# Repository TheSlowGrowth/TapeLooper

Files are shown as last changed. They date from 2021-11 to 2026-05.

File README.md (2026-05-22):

# TapeLooper





A digital tape looper module for Eurorack or standalone use, built on the [Daisy Seed](https://electro-smith.com/product/daisy-seed/).

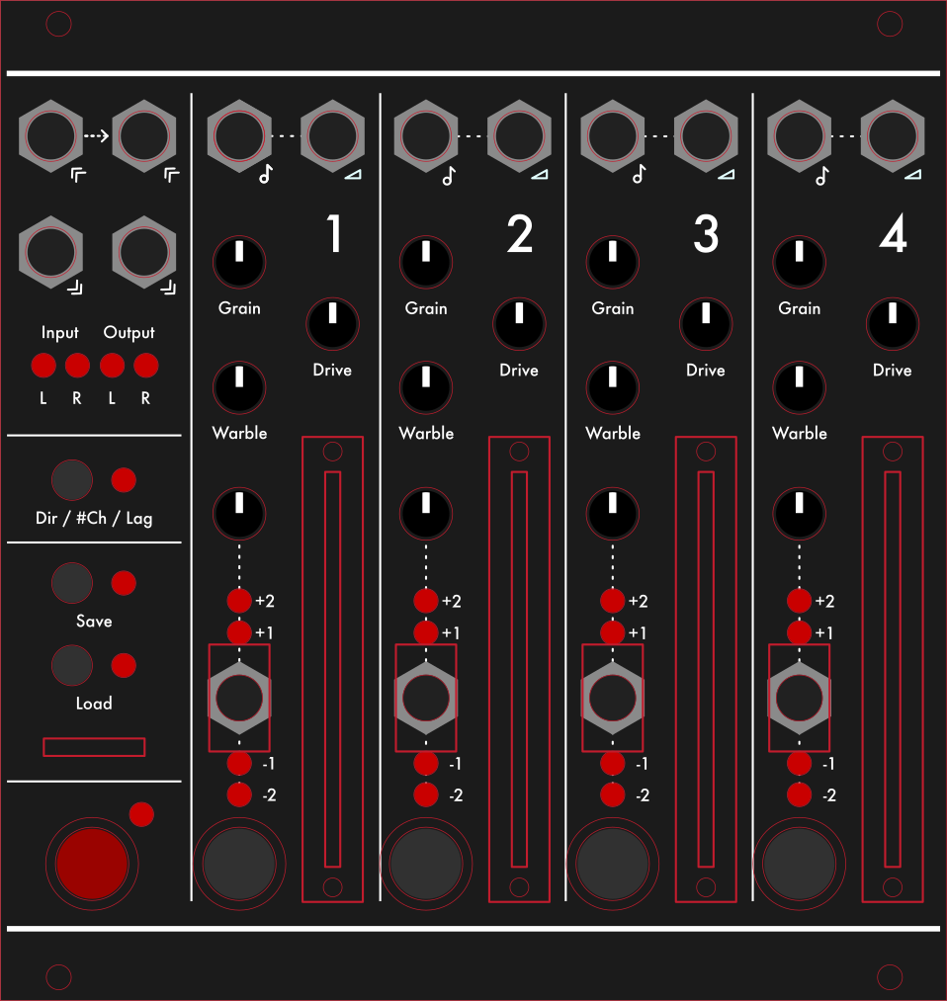
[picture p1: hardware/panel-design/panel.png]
panel design


## Features

- **4 stereo or mono tape loop channels** - record and play back independent, unsynchronized tape loops
- **Motor simulation** - playback speed ramps up and down with a configurable rate
- **Tape simulation** - with drive, grain and warble independently controllable
- **Variable playback speed** - with Volt/Octave CV control and quarter/half/double/quad speed
- **Forward and reverse playback**
- **Amplitude CV control**
- **Clean recording** — audio records cleanly into loop channels; tape simulation is applied during playback only
- **Perfect loop recording** - with a small crossfade at the loop point
- **SD card storage** - save and load loops as 48kHz stereo WAV files

## Hardware

Based on the Electrosmith Daisy Seed. Designed to operate as either a Eurorack module or a standalone desktop unit.

## Project Structure

- `dsp/` — DSP library: audio processing, loop playback/recording, tape simulation
- `firmware/` — Target firmware: main application, UI, SD card I/O
- `hardware/` — KiCad PCB designs and panel artwork
- `lib/` — External dependencies
- `scripts/` — Development helper scripts

## Development

### Requirements

- **CMake** 3.30+
- **clang++** (C++17) for building and running unit tests
- **arm-none-eabi-gcc** 10-2020-q4 recommended for cross-compiling firmware to the Daisy Seed
- **Python 3** with `pip` (for pre-commit hooks)

### Unit Tests

Tests are written with Google Test. Build and run from the respective `tests/` directories:

```bash
# DSP library tests
cd dsp/tests && make test

# Firmware tests
cd firmware/tests && make test
```

### Pre-commit Hook

A pre-commit hook runs `clang-format` on staged files before each commit. To install:

```bash
./scripts/setup-clangformat-precommit-hook.sh
```

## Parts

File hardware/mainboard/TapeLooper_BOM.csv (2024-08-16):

Reference | Value | Datasheet | Footprint | Qty | DNP
C101,C201,C401,C403 | 10u |  | Capacitor_SMD:C_0603_1608Metric_Pad1.08x0.95mm_HandSolder | 4
C102,C202,C402,C404,C601,C602,C603,C604,C702,C704,C803,C804,C808,C810,C903,C908 | 100n | -- mixed values -- | Capacitor_SMD:C_0603_1608Metric_Pad1.08x0.95mm_HandSolder | 16
C701,C703,C705,C706 | 560p |  | Capacitor_SMD:C_0603_1608Metric_Pad1.08x0.95mm_HandSolder | 4
C801,C805,C806,C811 | 4u7 | ~ | Capacitor_SMD:C_0603_1608Metric_Pad1.08x0.95mm_HandSolder | 4
C802,C807,C809 | 47u |  | Capacitor_SMD:CP_Elec_6.3x5.8 | 3
C901,C902,C904,C905,C906,C907,C909,C910 | 1n | ~ | Capacitor_SMD:C_0603_1608Metric_Pad1.08x0.95mm_HandSolder | 8
D201,D202,D203,D204,D205,D206,D207,D208,D401,D402,D403,D404,D405,D406,D407,D408,D409,D410,D411,D412,D413,D414,D415,D416 | LED_RED_GREEN_CA | ~ | LED_THT:LED_D3.0mm-3 | 24
D801,D802 | 1N5819 | http://www.vishay.com/docs/88525/1n5817.pdf | Diode_SMD:D_SOD-123 | 2
J101 | Micro_SD_Card | http://katalog.we-online.de/em/datasheet/693072010801.pdf | ell_connectors:PJS008U-3000 | 1
J701,J702,J703,J704,J901,J902,J903,J904,J905,J906,J907,J908 | PJ398SM |  | ell_connectors:THONKICONN | 12
J801 | Conn_02x05_Odd_Even | ~ | Connector_IDC:IDC-Header_2x05_P2.54mm_Vertical | 1
JP801 | SolderJumper_2_Bridged | ~ | Jumper:SolderJumper-2_P1.3mm_Bridged2Bar_RoundedPad1.0x1.5mm | 1
L801,L802 | Bead |  | Inductor_SMD:L_0603_1608Metric_Pad1.05x0.95mm_HandSolder | 2
L803,L804 | 4.7mH | ~ | Inductor_SMD:L_1210_3225Metric_Pad1.42x2.65mm_HandSolder | 2
R101,R102,R103,R104,R105,R106,R219 | 47k | ~ | Resistor_SMD:R_0603_1608Metric_Pad0.98x0.95mm_HandSolder | 7
R201,R202,R203,R204,R205,R206,R207,R208,R209,R210,R211,R212,R213,R214,R215,R216,R401,R402,R403,R404,R405,R406,R407,R408,R409,R410,R411,R412,R413,R414,R415,R416,R417,R418,R419,R420,R421,R422,R423,R424,R425,R426,R427,R428,R429,R430,R431,R432 | 330 | ~ | Resistor_SMD:R_0603_1608Metric_Pad0.98x0.95mm_HandSolder | 48
R217,R218 | 4k7 | ~ | Resistor_SMD:R_0603_1608Metric_Pad0.98x0.95mm_HandSolder | 2
R220,R221,R222,R223,R301,R302,R303,R304,R305,R306,R307,R308,R309,R310,R311,R312 | 10k | ~ | Resistor_SMD:R_0603_1608Metric_Pad0.98x0.95mm_HandSolder | 16
R701,R703,R707,R710,R901,R903,R907,R909,R913,R915,R919,R921 | 100k | -- mixed values -- | Resistor_SMD:R_0603_1608Metric_Pad0.98x0.95mm_HandSolder | 12
R702,R704,R706,R709 | 8k2 |  | Resistor_SMD:R_0603_1608Metric_Pad0.98x0.95mm_HandSolder | 4
R705,R708 | 1k |  | Resistor_SMD:R_0603_1608Metric_Pad0.98x0.95mm_HandSolder | 2
R801,R802 | 2k2 | ~ | Resistor_SMD:R_0603_1608Metric_Pad0.98x0.95mm_HandSolder | 2
R902,R908,R914,R920 | 78k7 | ~ | Resistor_SMD:R_0603_1608Metric_Pad0.98x0.95mm_HandSolder | 4
R904,R910,R916,R922 | 68k | ~ | Resistor_SMD:R_0603_1608Metric_Pad0.98x0.95mm_HandSolder | 4
R905,R911,R917,R923 | 481k | ~ | Resistor_SMD:R_0603_1608Metric_Pad0.98x0.95mm_HandSolder | 4
R906,R912,R918,R924 | 200k | ~ | Resistor_SMD:R_0603_1608Metric_Pad0.98x0.95mm_HandSolder | 4
RV501,RV502,RV503,RV504,RV509,RV510,RV511,RV512,RV513,RV514,RV515,RV516,RV517,RV518,RV519,RV520 | POTENTIOMETER |  | ell_passives:9mm_pot | 16
RV505,RV506,RV507,RV508 | PTA4543-2010CPB103 | ~ | Potentiometer_THT:Potentiometer_Bourns_PTA4543_Single_Slide | 4
SW201,SW202,SW203 | TL1105SPF250Q | ~ | Button_Switch_THT:SW_PUSH_6mm | 3
SW204 | D6R40F1LFS | ~ | ell_special:CK-D6R_Pushbutton | 1
SW301,SW303,SW305,SW307 | C&K 7105SYCQE | ~ | ell_special:7105SYCQE-1P3T-SP3T-Switch | 4
SW302,SW304,SW306,SW308 | D6R90F1LFS | ~ | ell_special:CK-D6R_Pushbutton | 4
U101 | DAISY_SEED |  | ell_special:Daisy_Seed | 1
U201,U401,U402 | PCA9685PW | http://www.nxp.com/documents/data_sheet/PCA9685.pdf | Package_SO:TSSOP-28_4.4x9.7mm_P0.65mm | 3
U601,U602,U603,U604 | 4051 | http://www.intersil.com/content/dam/Intersil/documents/cd40/cd4051bms-52bms-53bms.pdf | Package_SO:SO-16_3.9x9.9mm_P1.27mm | 4
U605,U606 | 74HC165 | https://assets.nexperia.com/documents/data-sheet/74HC_HCT165.pdf | Package_SO:SO-16_3.9x9.9mm_P1.27mm | 2
U701 | TL074 | -- mixed values -- | Package_SO:SOIC-14_3.9x8.7mm_P1.27mm | 1
U801 | LM4040DBZ-5 | http://www.ti.com/lit/ds/symlink/lm4040-n.pdf | Package_TO_SOT_SMD:SOT-23 | 1
U802,U804 | AZ1117-3.3 | https://www.diodes.com/assets/Datasheets/AZ1117.pdf | Package_TO_SOT_SMD:SOT-223-3_TabPin2 | 2
U803 | LM4040DBZ-10 | http://www.ti.com/lit/ds/symlink/lm4040-n.pdf | Package_TO_SOT_SMD:SOT-23 | 1
U805 | EC4SAW-24S05N |  | ell_special:EC4SAW_DC_DC_SIP8 | 1
U901,U902 | MCP6004 | http://ww1.microchip.com/downloads/en/DeviceDoc/21733j.pdf | Package_SO:SO-14_3.9x8.65mm_P1.27mm | 2

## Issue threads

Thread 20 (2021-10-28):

Check processing load on the ES Daisy board

TheSlowGrowth, 2021-10-28:
To understand how many channels we can do on the device, let's attempt to run the DSP code on the ES Daisy Seed and see how much channels we can handle concurrently.

TheSlowGrowth, 2021-11-20:
### Test results

from branch feature/TSG/hardware-performance-tests
- 4 stereo loopers
- 44.1kHz (requires [this PR in libDaisy](https://github.com/electro-smith/libDaisy/pull/438) to be merged)
- high shelf emphasis EQ removed to save cycles
- pre-gain removed to save cycles (it was unused anyway)
- mapping of UI controls is still missing

When all 4 loopers play back at 4x speed, we hit 90% processor utilisation. I think this could actually work :-)

Closed 2021-11-27.

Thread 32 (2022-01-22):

Replace JUCE plugin with VCV Rack module

TheSlowGrowth, 2022-01-22:
It makes a lot of sense to test the module in the form of a VCV Rack module plugin. We should replace the current JUCE plugin.

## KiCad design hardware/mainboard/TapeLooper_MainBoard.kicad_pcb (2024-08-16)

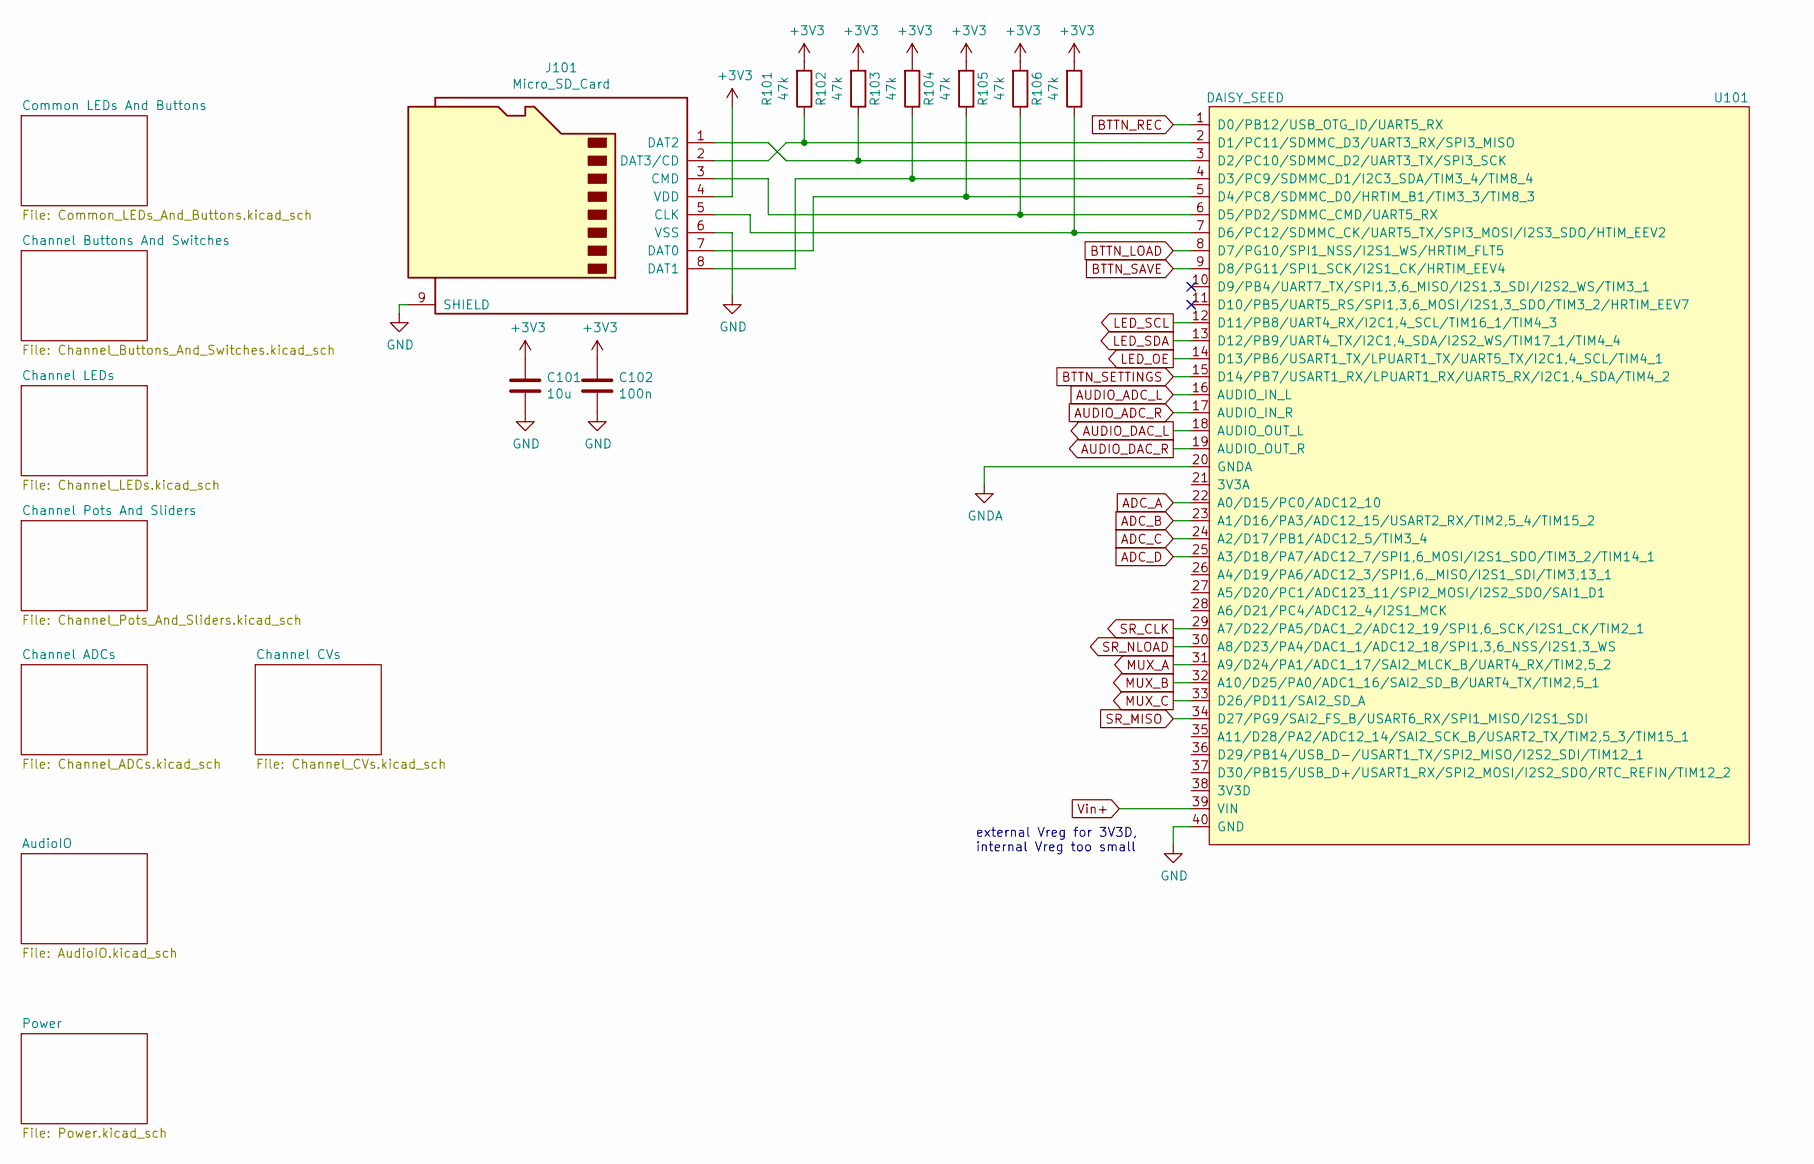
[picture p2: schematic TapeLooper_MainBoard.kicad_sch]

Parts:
C101: 10u; C_0603_1608Metric_Pad1.08x0.95mm_HandSolder
C102: 100n; C_0603_1608Metric_Pad1.08x0.95mm_HandSolder
J101: Micro_SD_Card; PJS008U-3000
R101, R102, R103, R104, R105, R106: 47k; R_0603_1608Metric_Pad0.98x0.95mm_HandSolder
U101: DAISY_SEED; Daisy_Seed

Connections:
+3V3: C101.1, C102.1, J101.4 (VDD), R101.2, R102.2, R103.2, R104.2, R105.2, R106.2; also elsewhere on the board
ADC_A: U101.22 (A0/D15/PC0/ADC12_10); also elsewhere on the board
ADC_B: U101.23 (A1/D16/PA3/ADC12_15/USART2_RX/TIM2,5_4/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); also elsewhere on the board
ADC_C: U101.24 (A2/D17/PB1/ADC12_5/TIM3_4); also elsewhere on the board
ADC_D: U101.25 (A3/D18/PA7/ADC12_7/SPI1,6_MOSI/I2S1_SDO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); also elsewhere on the board
AUDIO_ADC_L: U101.16 (AUDIO_IN_L); also elsewhere on the board
AUDIO_ADC_R: U101.17 (AUDIO_IN_R); also elsewhere on the board
AUDIO_DAC_L: U101.18 (AUDIO_OUT_L); also elsewhere on the board
AUDIO_DAC_R: U101.19 (AUDIO_OUT_R); also elsewhere on the board
BTTN_LOAD: U101.8 (D7/PG10/SPI1_NSS/I2S1_WS/HRTIM_FLT5); also elsewhere on the board
BTTN_REC: U101.1 (D0/PB12/USB_OTG_ID/UART5_RX); also elsewhere on the board
BTTN_SAVE: U101.9 (D8/PG11/SPI1_SCK/I2S1_CK/HRTIM_EEV4); also elsewhere on the board
BTTN_SETTINGS: U101.15 (D14/PB7/USART1_RX/LPUART1_RX/UART5_RX/I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); also elsewhere on the board
GND: C101.2, C102.2, J101.6 (VSS), J101.9 (SHIELD), U101.40 (GND); also elsewhere on the board
GNDA: U101.20 (GNDA); also elsewhere on the board
LED_OE: U101.14 (D13/PB6/USART1_TX/LPUART1_TX/UART5_TX/I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); also elsewhere on the board
LED_SCL: U101.12 (D11/PB8/UART4_RX/I2C1,4_SCL/TIM16_1/TIM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); also elsewhere on the board
LED_SDA: U101.13 (D12/PB9/UART4_TX/I2C1,4_SDA/I2S2_WS/TIM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); also elsewhere on the board
MUX_A: U101.31 (A9/D24/PA1/ADC1_17/SAI2_MLCK_B/UART4_RX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); also elsewhere on the board
MUX_B: U101.32 (A10/D25/PA0/ADC1_16/SAI2_SD_B/UART4_TX/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); also elsewhere on the board
MUX_C: U101.33 (D26/PD11/SAI2_SD_A); also elsewhere on the board
unnamed: J101.5 (CLK), R106.1, U101.7 (D6/PC12/SDMMC_CK/UART5_TX/SPI3_MOSI/I2S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)
unnamed: J101.3 (CMD), R105.1, U101.6 (D5/PD2/SDMMC_CMD/UART5_RX)
unnamed: J101.7 (DAT0), R104.1, U101.5 (D4/PC8/SDMMC_D0/HRTIM_B1/TIM3_3/TIM8_3)
unnamed: J101.8 (DAT1), R103.1, U101.4 (D3/PC9/SDMMC_D1/I2C3_SDA/TIM3_4/TIM8_4)
unnamed: J101.1 (DAT2), R102.1, U101.3 (D2/PC10/SDMMC_D2/UART3_TX/SPI3_SCK)
unnamed: J101.2 (DAT3/CD), R101.1, U101.2 (D1/PC11/SDMMC_D3/UART3_RX/SPI3_MISO)
SR_CLK: U101.29 (A7/D22/PA5/DAC1_2/ADC12_19/SPI1,6_SCK/I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); also elsewhere on the board
SR_MISO: U101.34 (D27/PG9/SAI2_FS_B/USART6_RX/SPI1_MISO/I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); also elsewhere on the board
SR_NLOAD: U101.30 (A8/D23/PA4/DAC1_1/ADC12_18/SPI1,3,6_NSS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); also elsewhere on the board
Vin+: U101.39 (VIN); also elsewhere on the board

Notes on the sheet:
external Vreg for 3V3D, internal Vreg too small

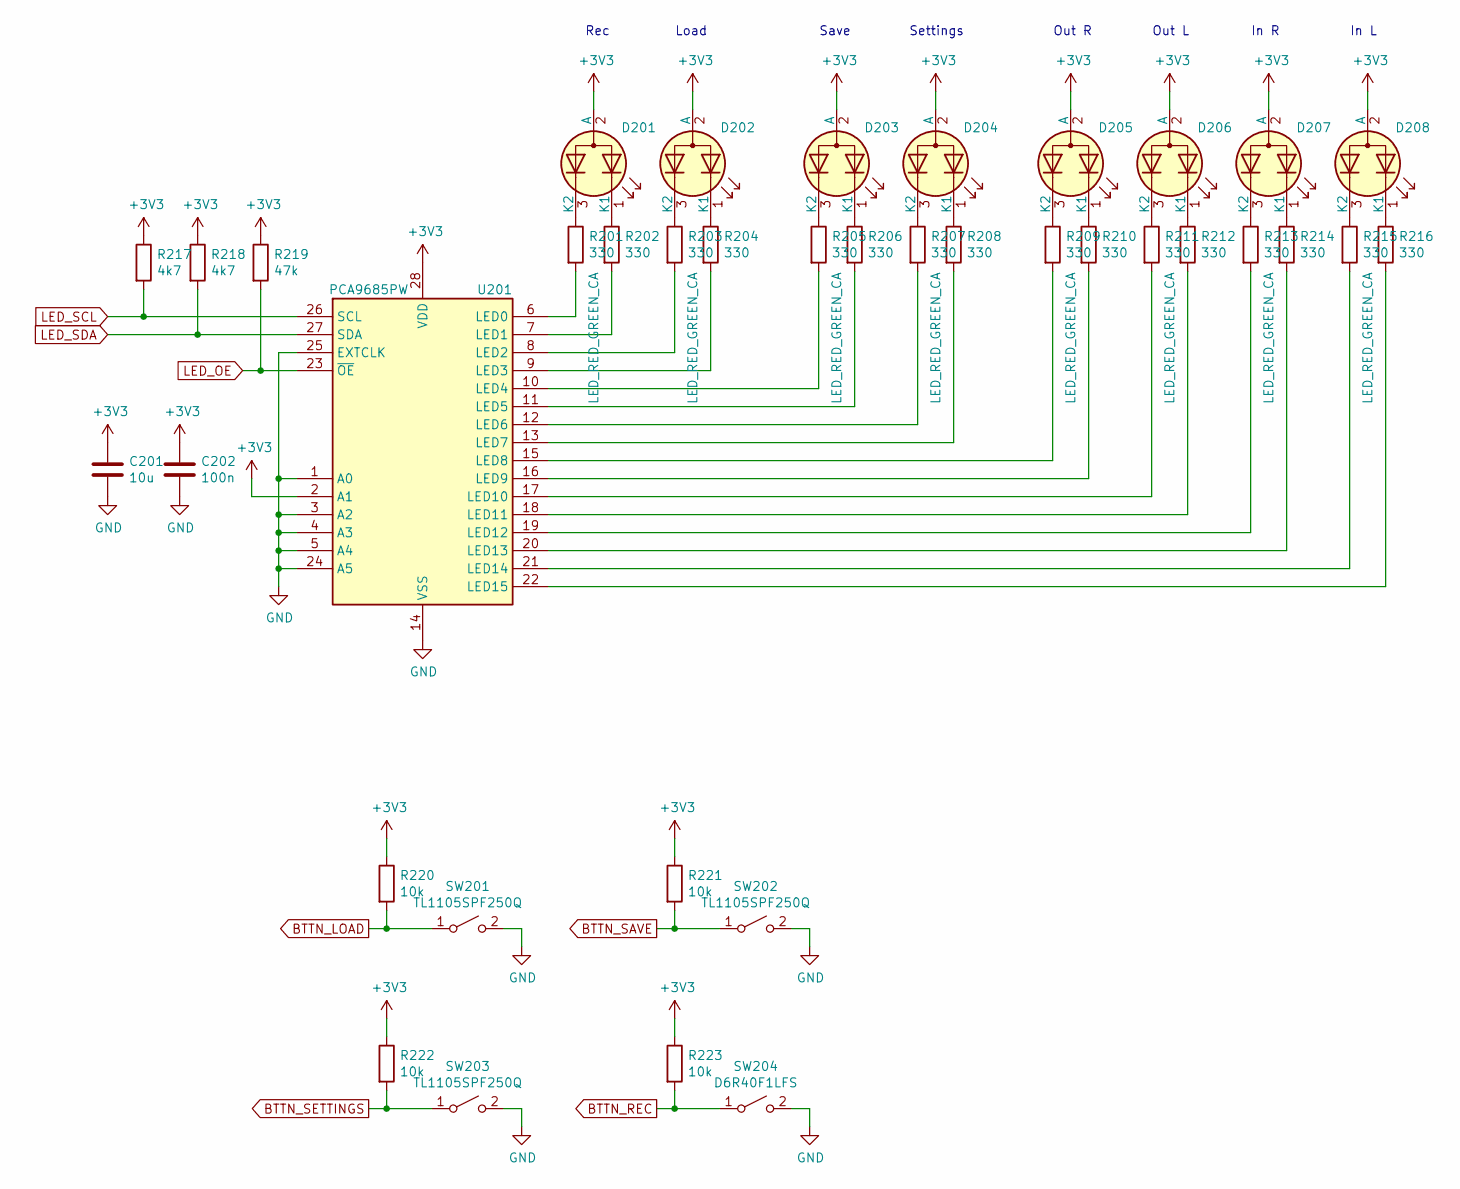
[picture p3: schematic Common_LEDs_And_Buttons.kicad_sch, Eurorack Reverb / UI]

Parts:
C201: 10u; C_0603_1608Metric_Pad1.08x0.95mm_HandSolder
C202: 100n; C_0603_1608Metric_Pad1.08x0.95mm_HandSolder
D201, D202, D203, D204, D205, D206, D207, D208: LED_RED_GREEN_CA; LED_D3.0mm-3
R201, R202, R203, R204, R205, R206, R207, R208, R209, R210, R211, R212, R213, R214, R215, R216: 330; R_0603_1608Metric_Pad0.98x0.95mm_HandSolder
R217, R218: 4k7; R_0603_1608Metric_Pad0.98x0.95mm_HandSolder
R219: 47k; R_0603_1608Metric_Pad0.98x0.95mm_HandSolder
R220, R221, R222, R223: 10k; R_0603_1608Metric_Pad0.98x0.95mm_HandSolder
SW201, SW202, SW203: TL1105SPF250Q; SW_PUSH_6mm
SW204: D6R40F1LFS; CK-D6R_Pushbutton
U201: PCA9685PW; TSSOP-28_4.4x9.7mm_P0.65mm

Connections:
+3V3: C201.1, C202.1, D201.2 (A), D202.2 (A), D203.2 (A), D204.2 (A), D205.2 (A), D206.2 (A), D207.2 (A), D208.2 (A), R217.1, R218.1, R219.1, R220.1, R221.1, R222.1, R223.1, U201.2 (A1), U201.28 (VDD); also elsewhere on the board
BTTN_LOAD: R220.2, SW201.1 (A); also elsewhere on the board
BTTN_REC: R223.2, SW204.1 (A); also elsewhere on the board
BTTN_SAVE: R221.2, SW202.1 (A); also elsewhere on the board
BTTN_SETTINGS: R222.2, SW203.1 (A); also elsewhere on the board
GND: C201.2, C202.2, SW201.2 (B), SW202.2 (B), SW203.2 (B), SW204.2 (B), U201.1 (A0), U201.3 (A2), U201.4 (A3), U201.5 (A4), U201.14 (VSS), U201.24 (A5), U201.25 (EXTCLK); also elsewhere on the board
LED_OE: R219.2, U201.23 (~OE); also elsewhere on the board
LED_SCL: R217.2, U201.26 (SCL); also elsewhere on the board
LED_SDA: R218.2, U201.27 (SDA); also elsewhere on the board
unnamed: D201.1 (K1), R202.1
unnamed: D201.3 (K2), R201.1
unnamed: D202.1 (K1), R204.1
unnamed: D202.3 (K2), R203.1
unnamed: D203.1 (K1), R206.1
unnamed: D203.3 (K2), R205.1
unnamed: D204.1 (K1), R208.1
unnamed: D204.3 (K2), R207.1
unnamed: D205.1 (K1), R210.1
unnamed: D205.3 (K2), R209.1
unnamed: D206.1 (K1), R212.1
unnamed: D206.3 (K2), R211.1
unnamed: D207.1 (K1), R214.1
unnamed: D207.3 (K2), R213.1
unnamed: D208.1 (K1), R216.1
unnamed: D208.3 (K2), R215.1
unnamed: R201.2, U201.6 (LED0)
unnamed: R202.2, U201.7 (LED1)
unnamed: R203.2, U201.8 (LED2)
unnamed: R204.2, U201.9 (LED3)
unnamed: R205.2, U201.10 (LED4)
unnamed: R206.2, U201.11 (LED5)
unnamed: R207.2, U201.12 (LED6)
unnamed: R208.2, U201.13 (LED7)
unnamed: R209.2, U201.15 (LED8)
unnamed: R210.2, U201.16 (LED9)
unnamed: R211.2, U201.17 (LED10)
unnamed: R212.2, U201.18 (LED11)
unnamed: R213.2, U201.19 (LED12)
unnamed: R214.2, U201.20 (LED13)
unnamed: R215.2, U201.21 (LED14)
unnamed: R216.2, U201.22 (LED15)

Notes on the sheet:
In R
Rec
Load
Out L
In L
Settings
Save
Out R

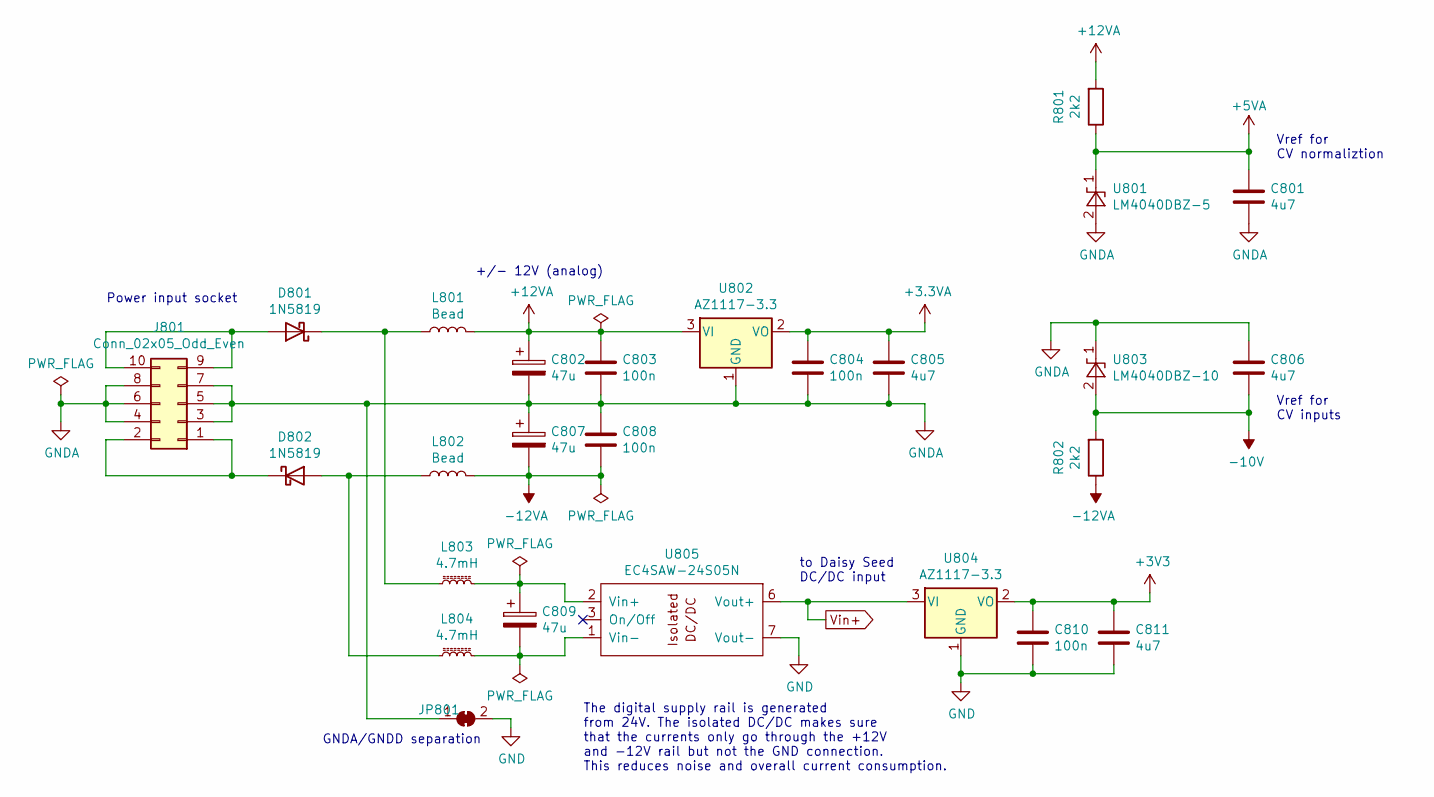
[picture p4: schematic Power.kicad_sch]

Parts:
C801, C805, C806, C811: 4u7; C_0603_1608Metric_Pad1.08x0.95mm_HandSolder
C802, C807, C809: 47u; CP_Elec_6.3x5.8
C803, C804, C808, C810: 100n; C_0603_1608Metric_Pad1.08x0.95mm_HandSolder
D801, D802: 1N5819; D_SOD-123
J801: Conn_02x05_Odd_Even; IDC-Header_2x05_P2.54mm_Vertical
JP801: SolderJumper_2_Bridged; SolderJumper-2_P1.3mm_Bridged2Bar_RoundedPad1.0x1.5mm
L801, L802: Bead; L_0603_1608Metric_Pad1.05x0.95mm_HandSolder
L803, L804: 4.7mH; L_1210_3225Metric_Pad1.42x2.65mm_HandSolder
R801, R802: 2k2; R_0603_1608Metric_Pad0.98x0.95mm_HandSolder
U801: LM4040DBZ-5; SOT-23
U802, U804: AZ1117-3.3; SOT-223-3_TabPin2
U803: LM4040DBZ-10; SOT-23
U805: EC4SAW-24S05N; EC4SAW_DC_DC_SIP8

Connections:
+3.3VA: C804.1, C805.1, U802.2 (VO); also elsewhere on the board
+3V3: C810.1, C811.1, U804.2 (VO); also elsewhere on the board
+5VA: C801.1, R801.1, U801.1 (K); also elsewhere on the board
+12VA: C802.1, C803.1, L801.2, R801.2, U802.3 (VI); also elsewhere on the board
-10V: C806.2, R802.2, U803.2 (A); also elsewhere on the board
-12VA: C807.2, C808.2, L802.2, R802.1; also elsewhere on the board
GND: C810.2, C811.2, JP801.2 (B), U804.1 (GND), U805.7 (Vout-); also elsewhere on the board
GNDA: C801.2, C802.2, C803.2, C804.2, C805.2, C806.1, C807.1, C808.1, J801.3, J801.4, J801.5, J801.6, J801.7, J801.8, JP801.1 (A), U801.2 (A), U802.1 (GND), U803.1 (K); also elsewhere on the board
unnamed: D801.2 (A), J801.9, J801.10
unnamed: D801.1 (K), L801.1, L803.1
unnamed: D802.2 (A), L802.1, L804.1
unnamed: D802.1 (K), J801.1, J801.2
unnamed: C809.1, L803.2, U805.2 (Vin+)
unnamed: C809.2, L804.2, U805.1 (Vin-)
Vin+: U804.3 (VI), U805.6 (Vout+); also elsewhere on the board

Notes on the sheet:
GNDA/GNDD separation
to Daisy Seed DC/DC input
The digital supply rail is generated from 24V. The isolated DC/DC makes sure that the currents only go through the +12V and -12V rail but not the GND connection. This reduces noise and overall current consumption.
Power input socket
Vref for CV normaliztion
+/- 12V (analog)
Vref for CV inputs

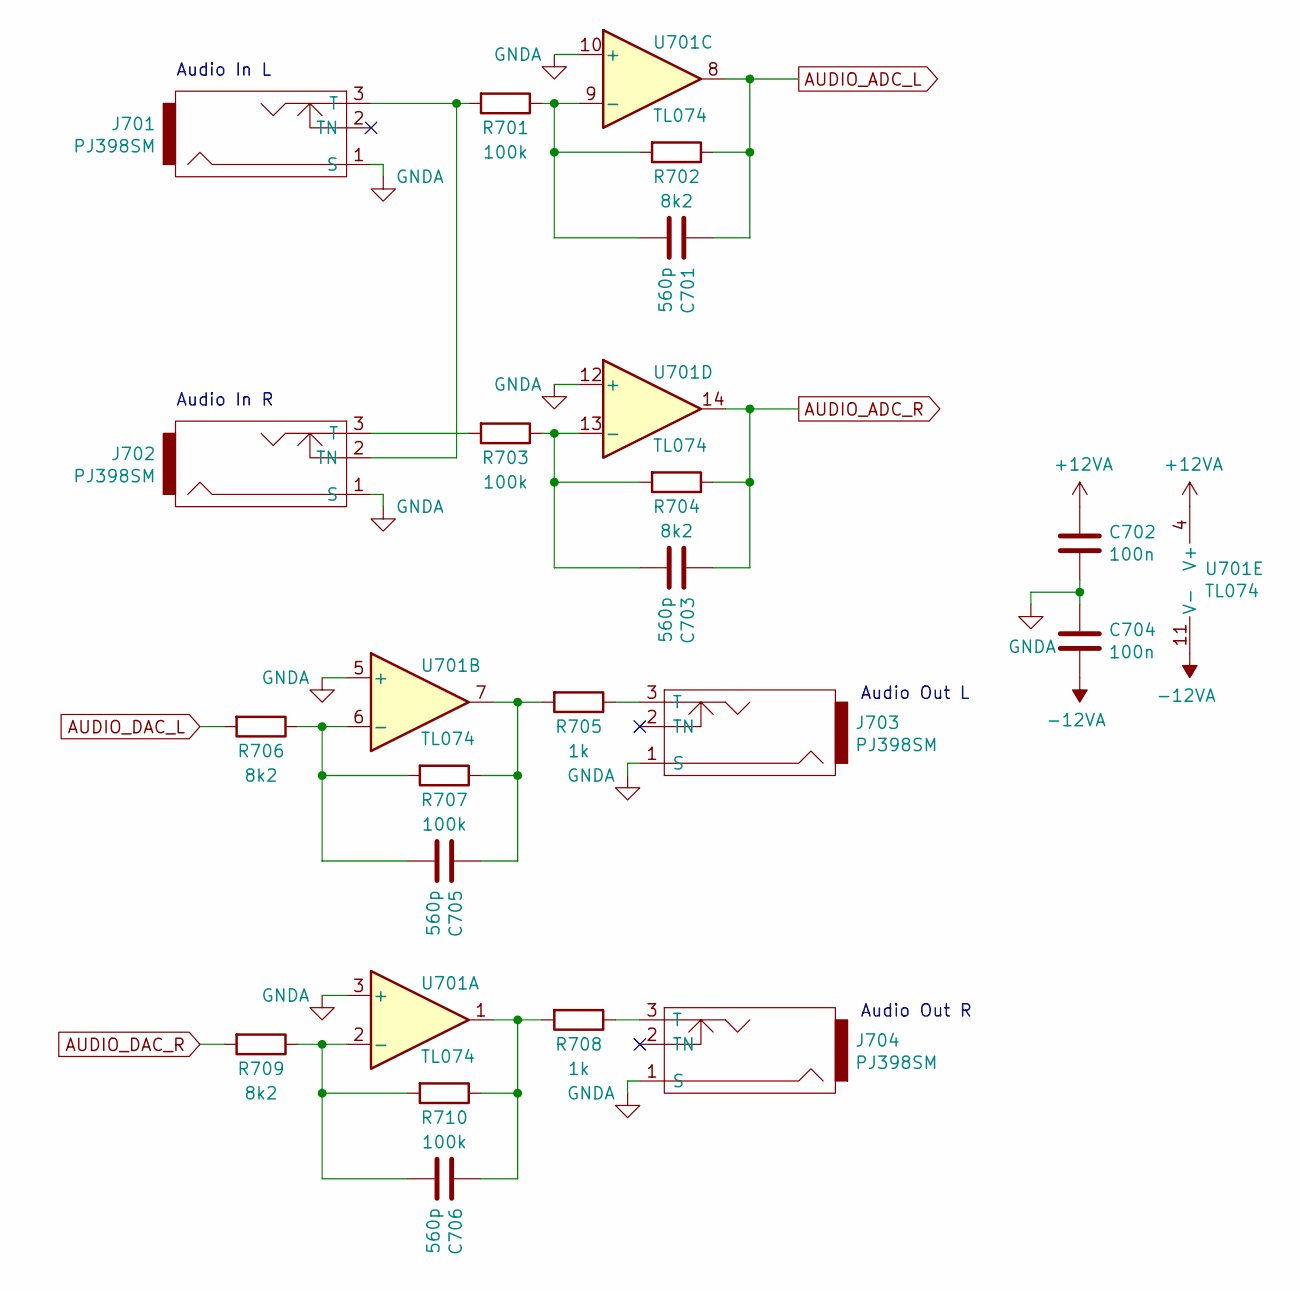
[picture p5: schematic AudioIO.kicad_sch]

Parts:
C701, C703, C705, C706: 560p; C_0603_1608Metric_Pad1.08x0.95mm_HandSolder
C702, C704: 100n; C_0603_1608Metric_Pad1.08x0.95mm_HandSolder
J701, J702, J703, J704: PJ398SM; THONKICONN
R701, R703, R707, R710: 100k; R_0603_1608Metric_Pad0.98x0.95mm_HandSolder
R702, R704, R706, R709: 8k2; R_0603_1608Metric_Pad0.98x0.95mm_HandSolder
R705, R708: 1k; R_0603_1608Metric_Pad0.98x0.95mm_HandSolder
U701: TL074; SOIC-14_3.9x8.7mm_P1.27mm

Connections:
+12VA: C702.1, U701.4 (V+); also elsewhere on the board
-12VA: C704.2, U701.11 (V-); also elsewhere on the board
AUDIO_ADC_L: C701.1, R702.1, U701.8; also elsewhere on the board
AUDIO_ADC_R: C703.1, R704.1, U701.14; also elsewhere on the board
AUDIO_DAC_L: R706.2; also elsewhere on the board
AUDIO_DAC_R: R709.2; also elsewhere on the board
GNDA: C702.2, C704.1, J701.1 (S), J702.1 (S), J703.1 (S), J704.1 (S), U701.3 (+), U701.5 (+), U701.10 (+), U701.12 (+); also elsewhere on the board
unnamed: C705.1, R705.2, R707.1, U701.7
unnamed: C706.1, R708.2, R710.1, U701.1
unnamed: J701.3 (T), J702.2 (TN), R701.2
unnamed: J702.3 (T), R703.2
unnamed: J703.3 (T), R705.1
unnamed: J704.3 (T), R708.1
unnamed: C706.2, R709.1, R710.2, U701.2 (-)
unnamed: C705.2, R706.1, R707.2, U701.6 (-)
unnamed: C701.2, R701.1, R702.2, U701.9 (-)
unnamed: C703.2, R703.1, R704.2, U701.13 (-)

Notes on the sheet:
Audio Out L
Audio In L
Audio In R
Audio Out R

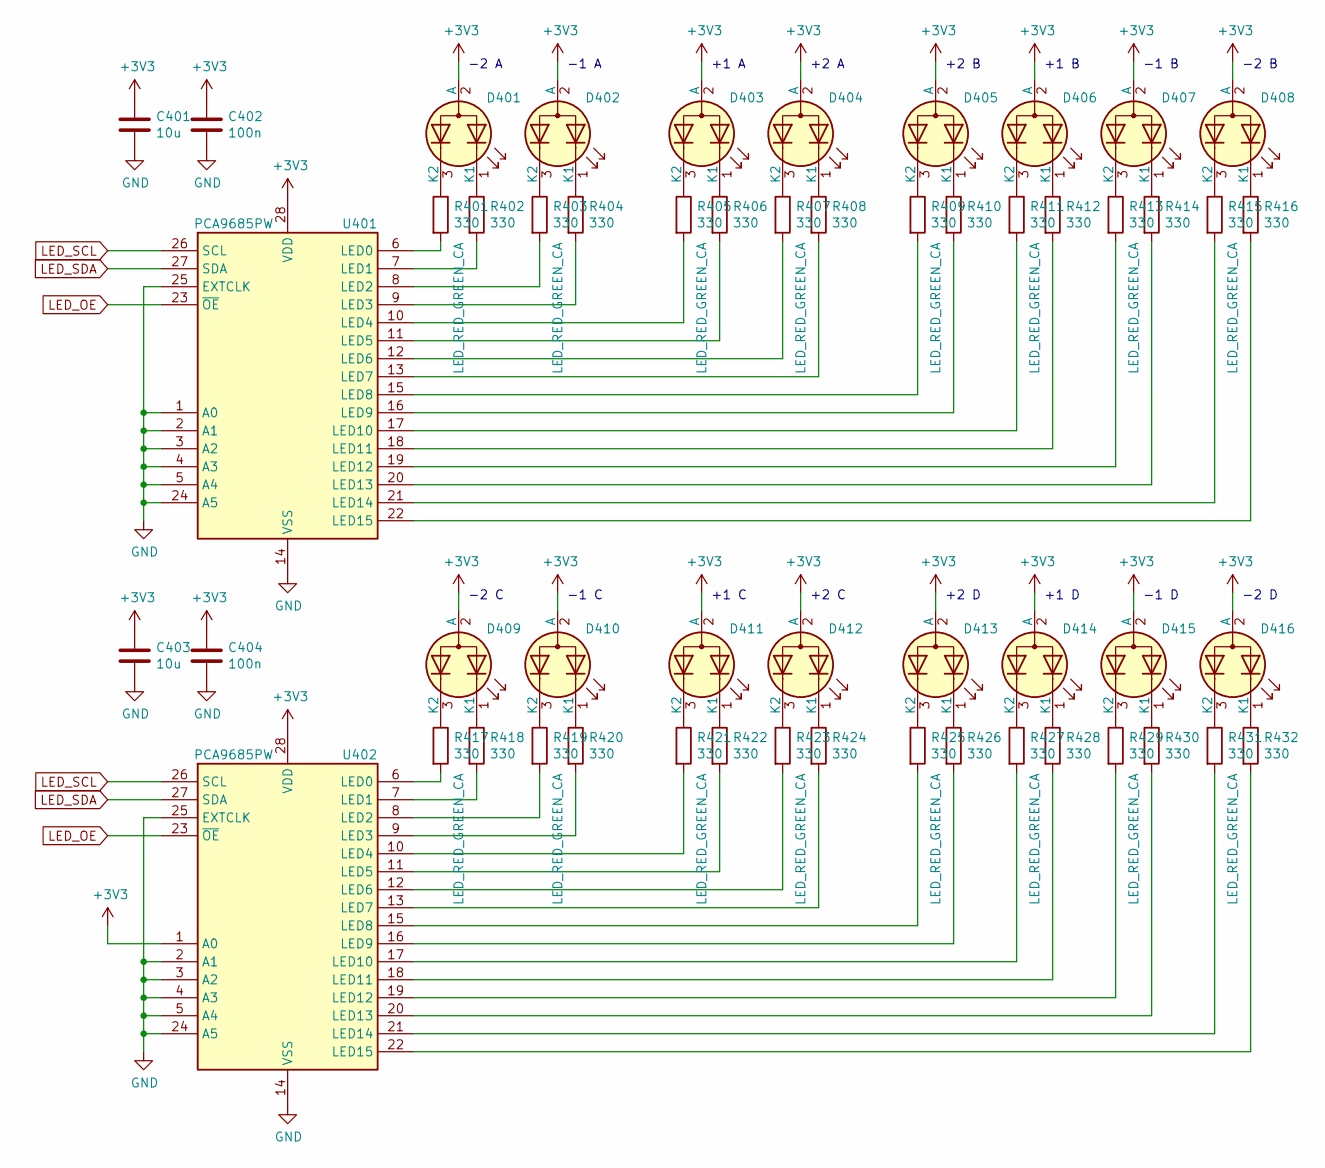
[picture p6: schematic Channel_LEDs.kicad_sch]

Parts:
C401, C403: 10u; C_0603_1608Metric_Pad1.08x0.95mm_HandSolder
C402, C404: 100n; C_0603_1608Metric_Pad1.08x0.95mm_HandSolder
D401, D402, D403, D404, D405, D406, D407, D408, D409, D410, D411, D412, D413, D414, D415, D416: LED_RED_GREEN_CA; LED_D3.0mm-3
R401, R402, R403, R404, R405, R406, R407, R408, R409, R410, R411, R412, R413, R414, R415, R416, R417, R418, R419, R420, R421, R422, R423, R424, R425, R426, R427, R428, R429, R430, R431, R432: 330; R_0603_1608Metric_Pad0.98x0.95mm_HandSolder
U401, U402: PCA9685PW; TSSOP-28_4.4x9.7mm_P0.65mm

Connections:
+3V3: C401.1, C402.1, C403.1, C404.1, D401.2 (A), D402.2 (A), D403.2 (A), D404.2 (A), D405.2 (A), D406.2 (A), D407.2 (A), D408.2 (A), D409.2 (A), D410.2 (A), D411.2 (A), D412.2 (A), D413.2 (A), D414.2 (A), D415.2 (A), D416.2 (A), U401.28 (VDD), U402.1 (A0), U402.28 (VDD); also elsewhere on the board
GND: C401.2, C402.2, C403.2, C404.2, U401.1 (A0), U401.2 (A1), U401.3 (A2), U401.4 (A3), U401.5 (A4), U401.14 (VSS), U401.24 (A5), U401.25 (EXTCLK), U402.2 (A1), U402.3 (A2), U402.4 (A3), U402.5 (A4), U402.14 (VSS), U402.24 (A5), U402.25 (EXTCLK); also elsewhere on the board
LED_OE: U401.23 (~OE), U402.23 (~OE); also elsewhere on the board
LED_SCL: U401.26 (SCL), U402.26 (SCL); also elsewhere on the board
LED_SDA: U401.27 (SDA), U402.27 (SDA); also elsewhere on the board
unnamed: D401.1 (K1), R402.1
unnamed: D401.3 (K2), R401.1
unnamed: D402.1 (K1), R404.1
unnamed: D402.3 (K2), R403.1
unnamed: D403.1 (K1), R406.1
unnamed: D403.3 (K2), R405.1
unnamed: D404.1 (K1), R408.1
unnamed: D404.3 (K2), R407.1
unnamed: D405.1 (K1), R410.1
unnamed: D405.3 (K2), R409.1
unnamed: D406.1 (K1), R412.1
unnamed: D406.3 (K2), R411.1
unnamed: D407.1 (K1), R414.1
unnamed: D407.3 (K2), R413.1
unnamed: D408.1 (K1), R416.1
unnamed: D408.3 (K2), R415.1
unnamed: D409.1 (K1), R418.1
unnamed: D409.3 (K2), R417.1
unnamed: D410.1 (K1), R420.1
unnamed: D410.3 (K2), R419.1
unnamed: D411.1 (K1), R422.1
unnamed: D411.3 (K2), R421.1
unnamed: D412.1 (K1), R424.1
unnamed: D412.3 (K2), R423.1
unnamed: D413.1 (K1), R426.1
unnamed: D413.3 (K2), R425.1
unnamed: D414.1 (K1), R428.1
unnamed: D414.3 (K2), R427.1
unnamed: D415.1 (K1), R430.1
unnamed: D415.3 (K2), R429.1
unnamed: D416.1 (K1), R432.1
unnamed: D416.3 (K2), R431.1
unnamed: R401.2, U401.6 (LED0)
unnamed: R402.2, U401.7 (LED1)
unnamed: R403.2, U401.8 (LED2)
unnamed: R404.2, U401.9 (LED3)
unnamed: R405.2, U401.10 (LED4)
unnamed: R406.2, U401.11 (LED5)
unnamed: R407.2, U401.12 (LED6)
unnamed: R408.2, U401.13 (LED7)
unnamed: R409.2, U401.15 (LED8)
unnamed: R410.2, U401.16 (LED9)
unnamed: R411.2, U401.17 (LED10)
unnamed: R412.2, U401.18 (LED11)
unnamed: R413.2, U401.19 (LED12)
unnamed: R414.2, U401.20 (LED13)
unnamed: R415.2, U401.21 (LED14)
unnamed: R416.2, U401.22 (LED15)
unnamed: R417.2, U402.6 (LED0)
unnamed: R418.2, U402.7 (LED1)
unnamed: R419.2, U402.8 (LED2)
unnamed: R420.2, U402.9 (LED3)
unnamed: R421.2, U402.10 (LED4)
unnamed: R422.2, U402.11 (LED5)
unnamed: R423.2, U402.12 (LED6)
unnamed: R424.2, U402.13 (LED7)
unnamed: R425.2, U402.15 (LED8)
unnamed: R426.2, U402.16 (LED9)
unnamed: R427.2, U402.17 (LED10)
unnamed: R428.2, U402.18 (LED11)
unnamed: R429.2, U402.19 (LED12)
unnamed: R430.2, U402.20 (LED13)
unnamed: R431.2, U402.21 (LED14)
unnamed: R432.2, U402.22 (LED15)

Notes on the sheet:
-2 A
+2 B
+1 A
-1 B
-2 C
-2 D
-1 A
-2 B
+2 C
+2 D
+1 D
+1 C
+2 A
+1 B
-1 C
-1 D

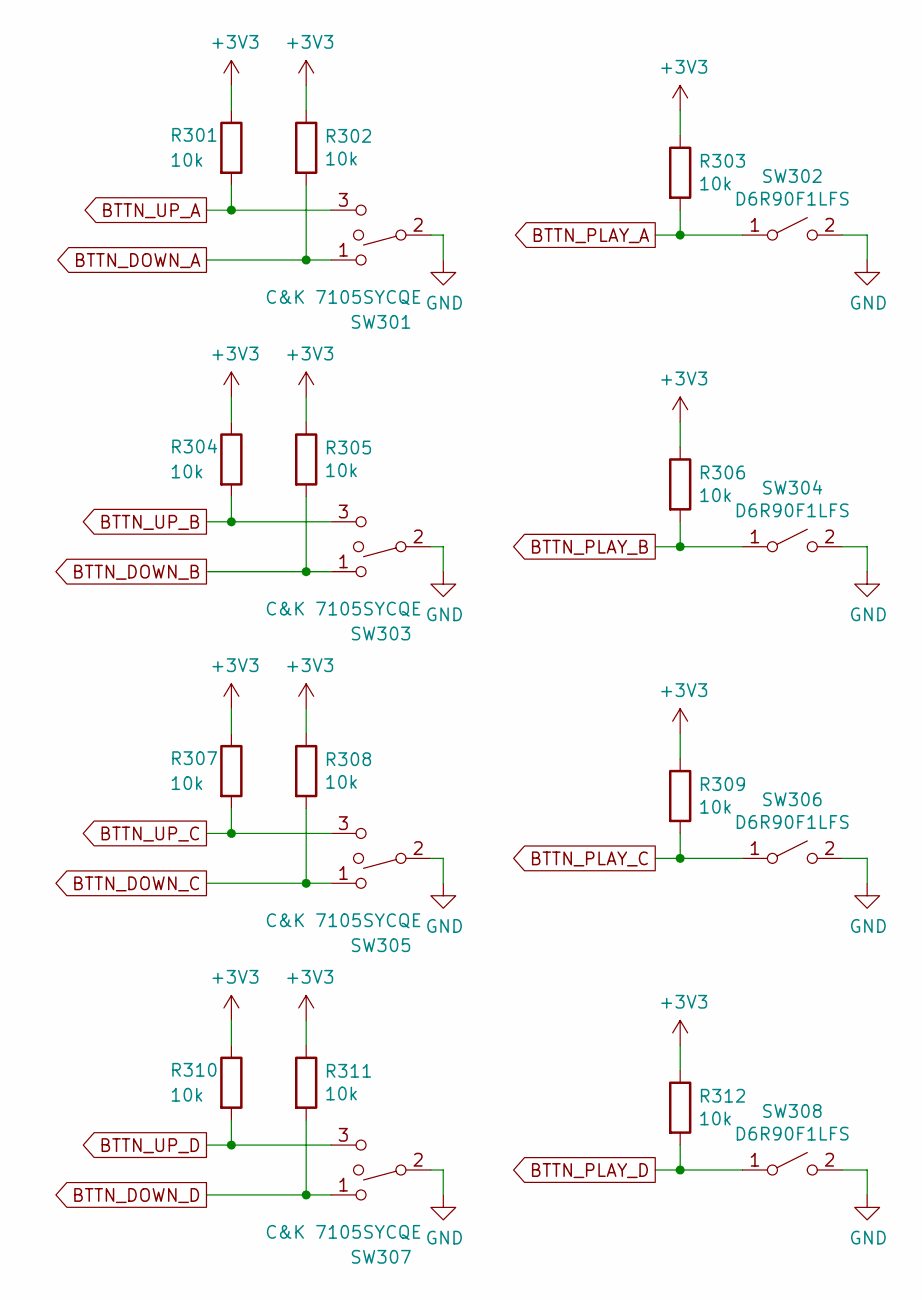
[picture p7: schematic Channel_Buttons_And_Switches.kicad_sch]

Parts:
R301, R302, R303, R304, R305, R306, R307, R308, R309, R310, R311, R312: 10k; R_0603_1608Metric_Pad0.98x0.95mm_HandSolder
SW301, SW303, SW305, SW307: C&K 7105SYCQE; 7105SYCQE-1P3T-SP3T-Switch
SW302, SW304, SW306, SW308: D6R90F1LFS; CK-D6R_Pushbutton

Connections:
+3V3: R301.1, R302.1, R303.1, R304.1, R305.1, R306.1, R307.1, R308.1, R309.1, R310.1, R311.1, R312.1; also elsewhere on the board
BTTN_DOWN_A: R302.2, SW301.1; also elsewhere on the board
BTTN_DOWN_B: R305.2, SW303.1; also elsewhere on the board
BTTN_DOWN_C: R308.2, SW305.1; also elsewhere on the board
BTTN_DOWN_D: R311.2, SW307.1; also elsewhere on the board
BTTN_PLAY_A: R303.2, SW302.1 (A); also elsewhere on the board
BTTN_PLAY_B: R306.2, SW304.1 (A); also elsewhere on the board
BTTN_PLAY_C: R309.2, SW306.1 (A); also elsewhere on the board
BTTN_PLAY_D: R312.2, SW308.1 (A); also elsewhere on the board
BTTN_UP_A: R301.2, SW301.3; also elsewhere on the board
BTTN_UP_B: R304.2, SW303.3; also elsewhere on the board
BTTN_UP_C: R307.2, SW305.3; also elsewhere on the board
BTTN_UP_D: R310.2, SW307.3; also elsewhere on the board
GND: SW301.2, SW302.2 (B), SW303.2, SW304.2 (B), SW305.2, SW306.2 (B), SW307.2, SW308.2 (B); also elsewhere on the board

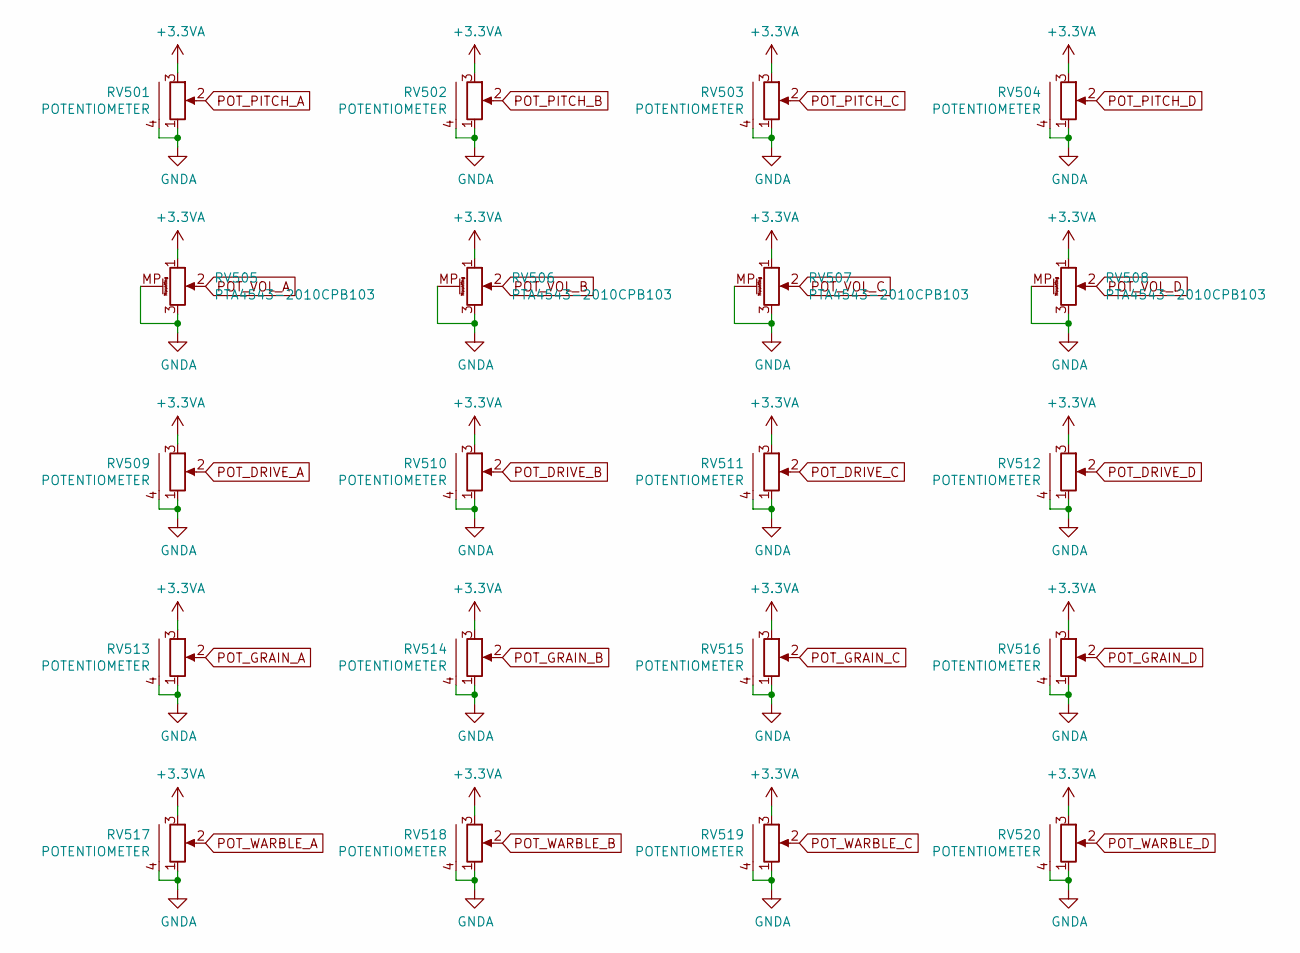
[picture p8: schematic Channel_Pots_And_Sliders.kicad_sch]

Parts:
RV501, RV502, RV503, RV504, RV509, RV510, RV511, RV512, RV513, RV514, RV515, RV516, RV517, RV518, RV519, RV520: POTENTIOMETER; 9mm_pot
RV505, RV506, RV507, RV508: PTA4543-2010CPB103; Potentiometer_Bourns_PTA4543_Single_Slide

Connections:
+3.3VA: RV501.3 (cw), RV502.3 (cw), RV503.3 (cw), RV504.3 (cw), RV505.1, RV506.1, RV507.1, RV508.1, RV509.3 (cw), RV510.3 (cw), RV511.3 (cw), RV512.3 (cw), RV513.3 (cw), RV514.3 (cw), RV515.3 (cw), RV516.3 (cw), RV517.3 (cw), RV518.3 (cw), RV519.3 (cw), RV520.3 (cw); also elsewhere on the board
GNDA: RV501.1 (ccw), RV501.4 (shield), RV502.1 (ccw), RV502.4 (shield), RV503.1 (ccw), RV503.4 (shield), RV504.1 (ccw), RV504.4 (shield), RV505.3, RV505.MP (MountPin), RV506.3, RV506.MP (MountPin), RV507.3, RV507.MP (MountPin), RV508.3, RV508.MP (MountPin), RV509.1 (ccw), RV509.4 (shield), RV510.1 (ccw), RV510.4 (shield), RV511.1 (ccw), RV511.4 (shield), RV512.1 (ccw), RV512.4 (shield), RV513.1 (ccw), RV513.4 (shield), RV514.1 (ccw), RV514.4 (shield), RV515.1 (ccw), RV515.4 (shield), RV516.1 (ccw), RV516.4 (shield), RV517.1 (ccw), RV517.4 (shield), RV518.1 (ccw), RV518.4 (shield), RV519.1 (ccw), RV519.4 (shield), RV520.1 (ccw), RV520.4 (shield); also elsewhere on the board
POT_DRIVE_A: RV509.2 (wiper); also elsewhere on the board
POT_DRIVE_B: RV510.2 (wiper); also elsewhere on the board
POT_DRIVE_C: RV511.2 (wiper); also elsewhere on the board
POT_DRIVE_D: RV512.2 (wiper); also elsewhere on the board
POT_GRAIN_A: RV513.2 (wiper); also elsewhere on the board
POT_GRAIN_B: RV514.2 (wiper); also elsewhere on the board
POT_GRAIN_C: RV515.2 (wiper); also elsewhere on the board
POT_GRAIN_D: RV516.2 (wiper); also elsewhere on the board
POT_PITCH_A: RV501.2 (wiper); also elsewhere on the board
POT_PITCH_B: RV502.2 (wiper); also elsewhere on the board
POT_PITCH_C: RV503.2 (wiper); also elsewhere on the board
POT_PITCH_D: RV504.2 (wiper); also elsewhere on the board
POT_VOL_A: RV505.2; also elsewhere on the board
POT_VOL_B: RV506.2; also elsewhere on the board
POT_VOL_C: RV507.2; also elsewhere on the board
POT_VOL_D: RV508.2; also elsewhere on the board
POT_WARBLE_A: RV517.2 (wiper); also elsewhere on the board
POT_WARBLE_B: RV518.2 (wiper); also elsewhere on the board
POT_WARBLE_C: RV519.2 (wiper); also elsewhere on the board
POT_WARBLE_D: RV520.2 (wiper); also elsewhere on the board

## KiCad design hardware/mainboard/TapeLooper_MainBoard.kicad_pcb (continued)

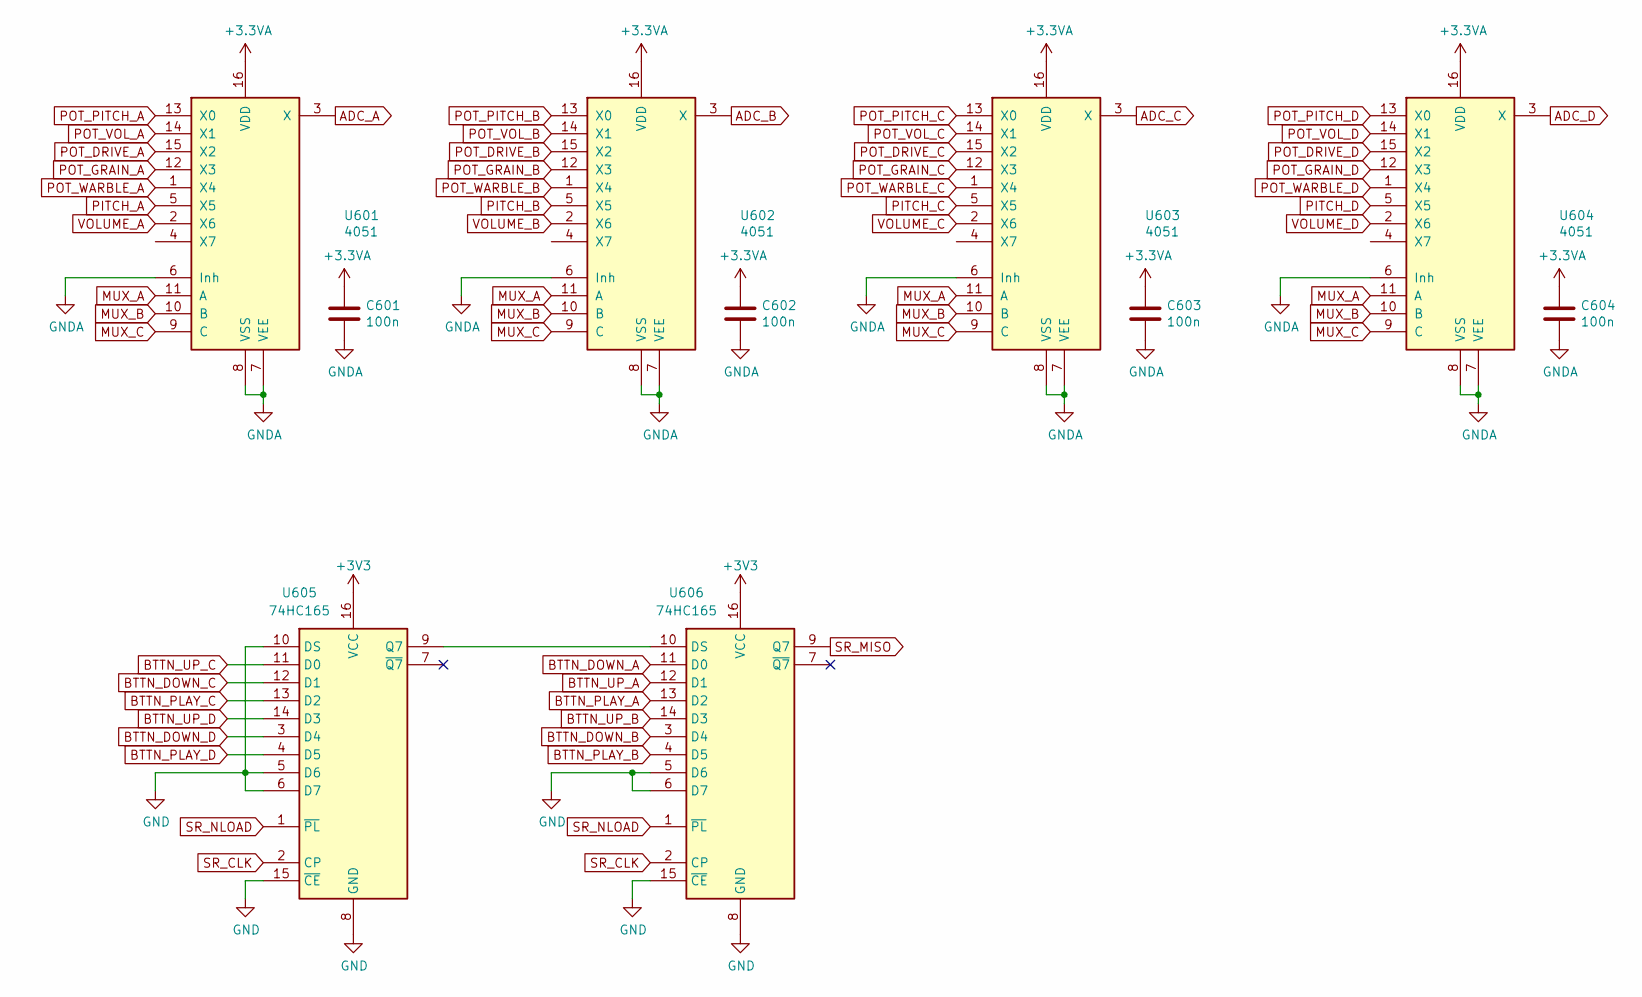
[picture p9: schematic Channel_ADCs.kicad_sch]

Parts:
C601, C602, C603, C604: 100n; C_0603_1608Metric_Pad1.08x0.95mm_HandSolder
U601, U602, U603, U604: 4051; SO-16_3.9x9.9mm_P1.27mm
U605, U606: 74HC165; SO-16_3.9x9.9mm_P1.27mm

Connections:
+3.3VA: C601.1, C602.1, C603.1, C604.1, U601.16 (VDD), U602.16 (VDD), U603.16 (VDD), U604.16 (VDD); also elsewhere on the board
+3V3: U605.16 (VCC), U606.16 (VCC); also elsewhere on the board
ADC_A: U601.3 (X); also elsewhere on the board
ADC_B: U602.3 (X); also elsewhere on the board
ADC_C: U603.3 (X); also elsewhere on the board
ADC_D: U604.3 (X); also elsewhere on the board
BTTN_DOWN_A: U606.11 (D0); also elsewhere on the board
BTTN_DOWN_B: U606.3 (D4); also elsewhere on the board
BTTN_DOWN_C: U605.12 (D1); also elsewhere on the board
BTTN_DOWN_D: U605.3 (D4); also elsewhere on the board
BTTN_PLAY_A: U606.13 (D2); also elsewhere on the board
BTTN_PLAY_B: U606.4 (D5); also elsewhere on the board
BTTN_PLAY_C: U605.13 (D2); also elsewhere on the board
BTTN_PLAY_D: U605.4 (D5); also elsewhere on the board
BTTN_UP_A: U606.12 (D1); also elsewhere on the board
BTTN_UP_B: U606.14 (D3); also elsewhere on the board
BTTN_UP_C: U605.11 (D0); also elsewhere on the board
BTTN_UP_D: U605.14 (D3); also elsewhere on the board
GND: U605.5 (D6), U605.6 (D7), U605.8 (GND), U605.10 (DS), U605.15 (~CE), U606.5 (D6), U606.6 (D7), U606.8 (GND), U606.15 (~CE); also elsewhere on the board
GNDA: C601.2, C602.2, C603.2, C604.2, U601.6 (Inh), U601.7 (VEE), U601.8 (VSS), U602.6 (Inh), U602.7 (VEE), U602.8 (VSS), U603.6 (Inh), U603.7 (VEE), U603.8 (VSS), U604.6 (Inh), U604.7 (VEE), U604.8 (VSS); also elsewhere on the board
MUX_A: U601.11 (A), U602.11 (A), U603.11 (A), U604.11 (A); also elsewhere on the board
MUX_B: U601.10 (B), U602.10 (B), U603.10 (B), U604.10 (B); also elsewhere on the board
MUX_C: U601.9 (C), U602.9 (C), U603.9 (C), U604.9 (C); also elsewhere on the board
unnamed: U605.9 (Q7), U606.10 (DS)
PITCH_A: U601.5 (X5); also elsewhere on the board
PITCH_B: U602.5 (X5); also elsewhere on the board
PITCH_C: U603.5 (X5); also elsewhere on the board
PITCH_D: U604.5 (X5); also elsewhere on the board
POT_DRIVE_A: U601.15 (X2); also elsewhere on the board
POT_DRIVE_B: U602.15 (X2); also elsewhere on the board
POT_DRIVE_C: U603.15 (X2); also elsewhere on the board
POT_DRIVE_D: U604.15 (X2); also elsewhere on the board
POT_GRAIN_A: U601.12 (X3); also elsewhere on the board
POT_GRAIN_B: U602.12 (X3); also elsewhere on the board
POT_GRAIN_C: U603.12 (X3); also elsewhere on the board
POT_GRAIN_D: U604.12 (X3); also elsewhere on the board
POT_PITCH_A: U601.13 (X0); also elsewhere on the board
POT_PITCH_B: U602.13 (X0); also elsewhere on the board
POT_PITCH_C: U603.13 (X0); also elsewhere on the board
POT_PITCH_D: U604.13 (X0); also elsewhere on the board
POT_VOL_A: U601.14 (X1); also elsewhere on the board
POT_VOL_B: U602.14 (X1); also elsewhere on the board
POT_VOL_C: U603.14 (X1); also elsewhere on the board
POT_VOL_D: U604.14 (X1); also elsewhere on the board
POT_WARBLE_A: U601.1 (X4); also elsewhere on the board
POT_WARBLE_B: U602.1 (X4); also elsewhere on the board
POT_WARBLE_C: U603.1 (X4); also elsewhere on the board
POT_WARBLE_D: U604.1 (X4); also elsewhere on the board
SR_CLK: U605.2 (CP), U606.2 (CP); also elsewhere on the board
SR_MISO: U606.9 (Q7); also elsewhere on the board
SR_NLOAD: U605.1 (~PL), U606.1 (~PL); also elsewhere on the board
VOLUME_A: U601.2 (X6); also elsewhere on the board
VOLUME_B: U602.2 (X6); also elsewhere on the board
VOLUME_C: U603.2 (X6); also elsewhere on the board
VOLUME_D: U604.2 (X6); also elsewhere on the board

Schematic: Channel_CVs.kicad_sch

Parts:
C901, C902, C904, C905, C906, C907, C909, C910: 1n; C_0603_1608Metric_Pad1.08x0.95mm_HandSolder
C903, C908: 100n; C_0603_1608Metric_Pad1.08x0.95mm_HandSolder
J901, J902, J903, J904, J905, J906, J907, J908: PJ398SM; THONKICONN
R901, R903, R907, R909, R913, R915, R919, R921: 100k; R_0603_1608Metric_Pad0.98x0.95mm_HandSolder
R902, R908, R914, R920: 78k7; R_0603_1608Metric_Pad0.98x0.95mm_HandSolder
R904, R910, R916, R922: 68k; R_0603_1608Metric_Pad0.98x0.95mm_HandSolder
R905, R911, R917, R923: 481k; R_0603_1608Metric_Pad0.98x0.95mm_HandSolder
R906, R912, R918, R924: 200k; R_0603_1608Metric_Pad0.98x0.95mm_HandSolder
U901, U902: MCP6004; SO-14_3.9x8.65mm_P1.27mm

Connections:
+3.3VA: C903.1, C908.1, U901.4 (V+), U902.4 (V+); also elsewhere on the board
+5VA: J902.2 (TN), J904.2 (TN), J906.2 (TN), J908.2 (TN); also elsewhere on the board
-10V: R905.2, R906.2, R911.2, R912.2, R917.2, R918.2, R923.2, R924.2; also elsewhere on the board
GNDA: C903.2, C908.2, J901.1 (S), J901.2 (TN), J902.1 (S), J903.1 (S), J903.2 (TN), J904.1 (S), J905.1 (S), J905.2 (TN), J906.1 (S), J907.1 (S), J907.2 (TN), J908.1 (S), U901.3 (+), U901.5 (+), U901.10 (+), U901.11 (V-), U901.12 (+), U902.3 (+), U902.5 (+), U902.10 (+), U902.11 (V-), U902.12 (+); also elsewhere on the board
unnamed: J901.3 (T), R901.1
unnamed: J902.3 (T), R903.1
unnamed: J903.3 (T), R907.1
unnamed: J904.3 (T), R909.1
unnamed: J905.3 (T), R913.1
unnamed: J906.3 (T), R915.1
unnamed: J907.3 (T), R919.1
unnamed: J908.3 (T), R921.1
unnamed: C901.1, R901.2, R902.1, R905.1, U901.2 (-)
unnamed: C902.1, R903.2, R904.1, R906.1, U901.6 (-)
unnamed: C904.1, R907.2, R908.1, R911.1, U901.9 (-)
unnamed: C905.1, R909.2, R910.1, R912.1, U901.13 (-)
unnamed: C906.1, R913.2, R914.1, R917.1, U902.2 (-)
unnamed: C907.1, R915.2, R916.1, R918.1, U902.6 (-)
unnamed: C909.1, R919.2, R920.1, R923.1, U902.9 (-)
unnamed: C910.1, R921.2, R922.1, R924.1, U902.13 (-)
PITCH_A: C901.2, R902.2, U901.1; also elsewhere on the board
PITCH_B: C904.2, R908.2, U901.8; also elsewhere on the board
PITCH_C: C906.2, R914.2, U902.1; also elsewhere on the board
PITCH_D: C909.2, R920.2, U902.8; also elsewhere on the board
VOLUME_A: C902.2, R904.2, U901.7; also elsewhere on the board
VOLUME_B: C905.2, R910.2, U901.14; also elsewhere on the board
VOLUME_C: C907.2, R916.2, U902.7; also elsewhere on the board
VOLUME_D: C910.2, R922.2, U902.14; also elsewhere on the board

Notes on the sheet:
Pitch D
Pitch B
Volume D
-2 .. 2V
Volume A
Pitch C
0 .. 5V
Volume B
Pitch A
Volume C

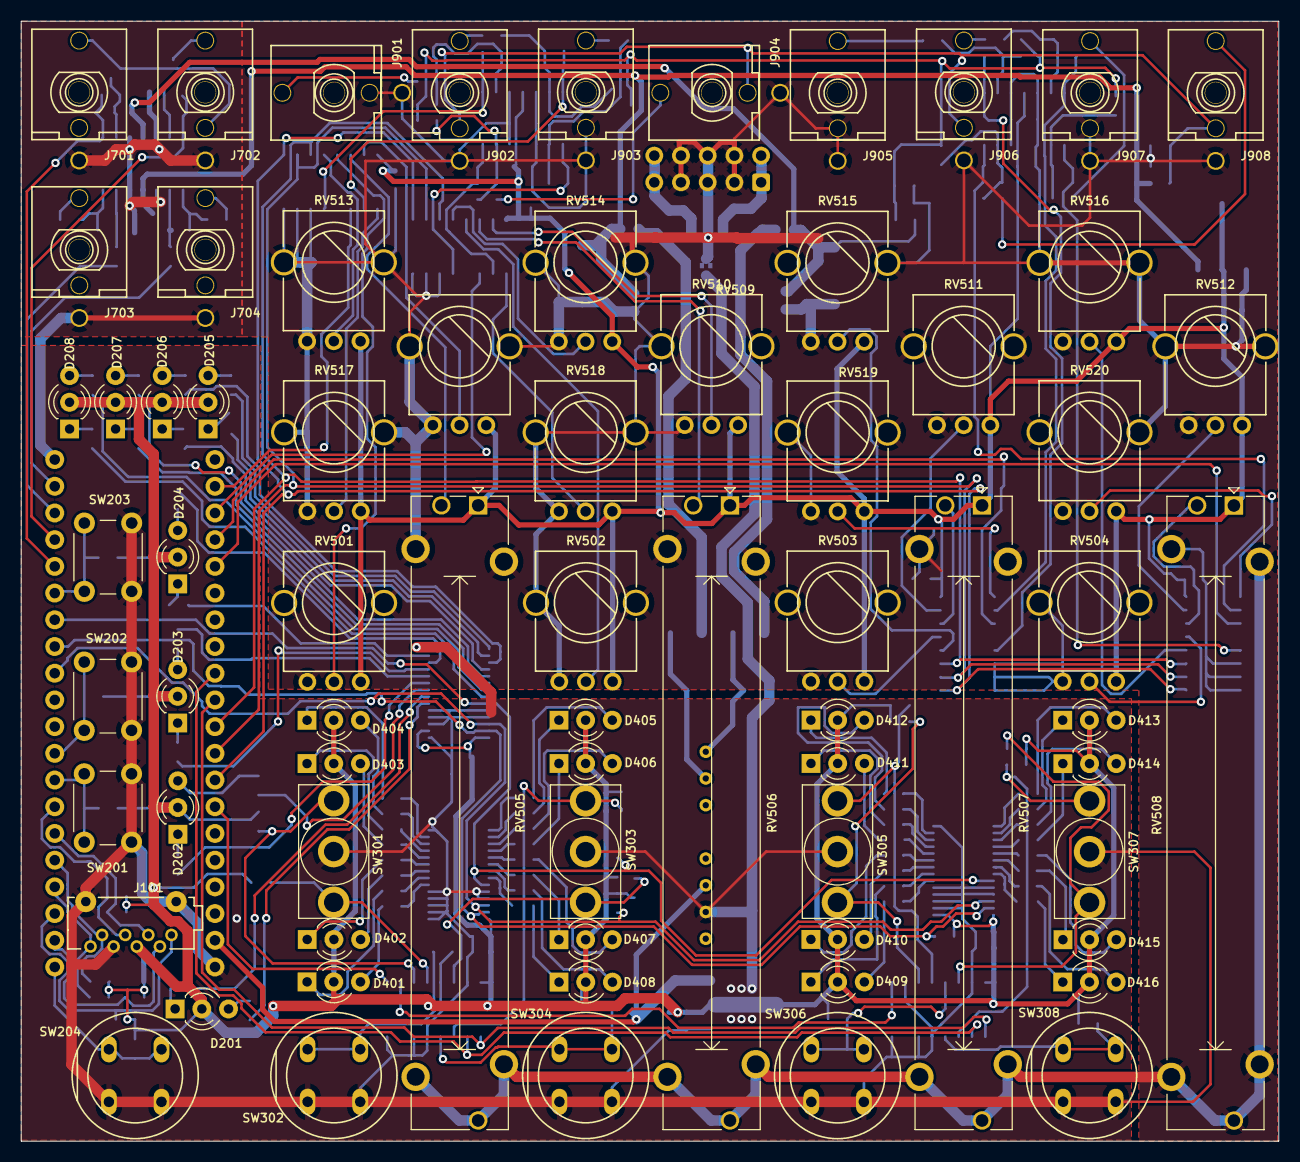
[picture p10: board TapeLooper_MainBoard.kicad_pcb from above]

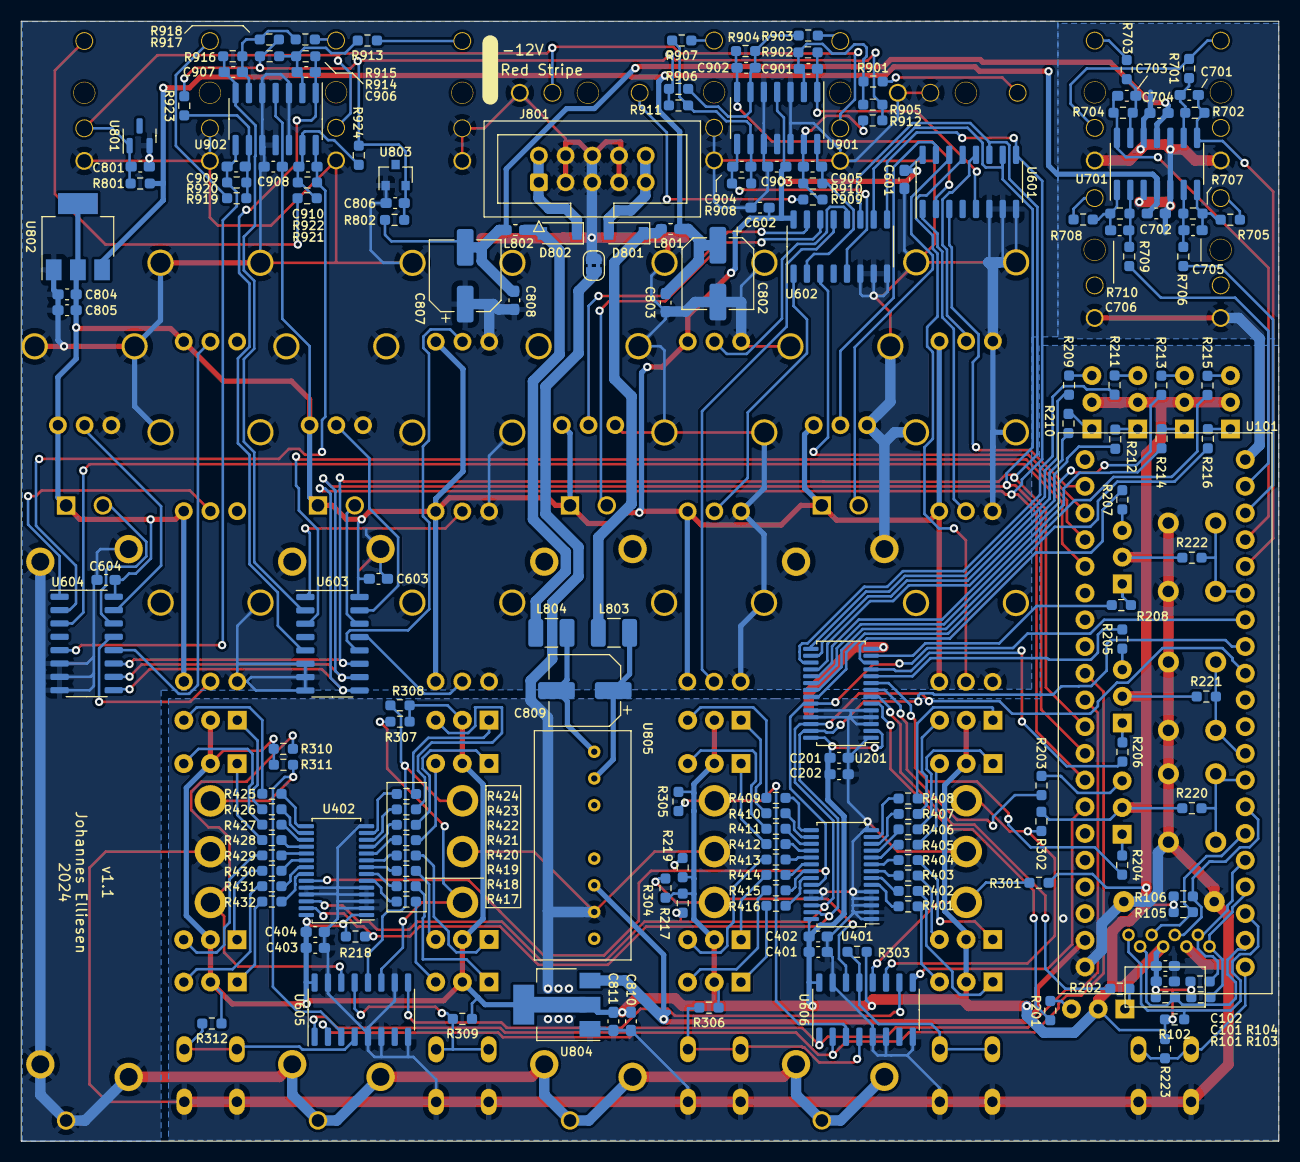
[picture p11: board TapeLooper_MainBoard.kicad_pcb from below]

Board: 2 copper layers, 119.6 x 106.5 mm, 243 parts (174 on the bottom side), 205 nets.

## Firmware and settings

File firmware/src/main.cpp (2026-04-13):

/**
 * Copyright (C) Johannes Elliesen, 2021
 *
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
 * You should have received a copy of the GNU General Public License
 * along with this program. If not, see <http://www.gnu.org/licenses/>.
 */

#define MANUAL_INLINE inline __attribute__((always_inline))

#include "daisy_seed.h"

#include "constants.h"
#include "dsp/PeakMeter.h"
#include "hardware/FatFsFileIo.h"
#include "hardware/UiHardware.h"
#include "ui/TapeLooperUi.h"
#include "dsp/TapeLooper.h"
#include "util/LateInitializedObject.h"
#include "LooperController.h"
#include "ui/LooperParameterProvider.h"

#define EXTERNAL_SDRAM_SECTION __attribute__((section(".sdram_bss")))

// type definitions
using LooperParameterProviderType = LooperParameterProvider<numLoopers>;
struct LooperTypes
{
    using MonoLooperType = TapeLooper<sampleRateHz, 1>;
    using StereoLooperType = TapeLooper<sampleRateHz, 2>;
    using ParameterProvider = LooperParameterProviderType;
    using AudioSaveAndRecallType = AudioSaveAndRecall<FatFsFileIo>;
};
using LooperControllerType = LooperController<LooperTypes, numLoopers>;
using LoopLibraryType = loop_library::Library<FatFsFileIo>;

using TapeLooperUiType = TapeLooperUi<UiHardware,
                                      PeakMeter<blockSize, sampleRateHz>,
                                      LooperControllerType,
                                      LooperParameterProviderType,
                                      LoopLibraryType>;
using LooperStoragesType = std::array<MonoOrStereoLooperStorage<looperSamplesPerChannel>, numLoopers>;

// hardware static objects
daisy::DaisySeed seed;

// ui static objects
daisy::UiEventQueue uiEventQueue;
UiHardware::LedDmaBufferType DMA_BUFFER_MEM_SECTION ledDmaBufferA, ledDmaBufferB;
uint16_t DMA_BUFFER_MEM_SECTION buttonShiftRegisterDmaBuffer;

LateInitializedObject<FatFsFileIo> fileIo;
LateInitializedObject<UiHardware> uiHardware;
LateInitializedObject<LoopLibraryType> loopLibrary;
LateInitializedObject<TapeLooperUiType> ui;

// dsp static objects
std::array<PeakMeter<blockSize, sampleRateHz>, 4> peakMeters;
#define EXTERNAL_SDRAM_SECTION __attribute__((section(".sdram_bss")))
LateInitializedObject<LooperStoragesType> EXTERNAL_SDRAM_SECTION looperStorages;
LateInitializedObject<LooperParameterProviderType> looperParameterProvider;
LateInitializedObject<LooperTypes::AudioSaveAndRecallType> audioSaveAndRecall;
AudioBuffer<1, blockSize> monoDownmixBuffer;
AudioBuffer<1, blockSize> temporaryBuffer;
LateInitializedObject<LooperControllerType> looperController;

// misc
daisy::CpuLoadMeter cpuLoadMeter;

// ===================================================================
// UI
// ===================================================================

void clearLedDisplay(const daisy::UiCanvasDescriptor&)
{
    uiHardware->clearLeds();
}

void flushLedDisplay(const daisy::UiCanvasDescriptor&)
{
    uiHardware->transmitLeds();
}

void initUi()
{
    // init the UI hardware
    auto& hardware = *uiHardware.create(seed.qspi,
                                        uiEventQueue,
                                        ledDmaBufferA,
                                        ledDmaBufferB,
                                        &buttonShiftRegisterDmaBuffer);

    loopLibrary.create(fileIo);

    // init the UI
    ui.create(
        hardware,
        &clearLedDisplay,
        &flushLedDisplay,
        uiEventQueue,
        peakMeters,
        looperController,
        looperParameterProvider,
        loopLibrary);
}

// ===================================================================
// DSP Init
// ===================================================================

void initDsp()
{
    looperParameterProvider.create();

    audioSaveAndRecall.create(fileIo);

    // initialize the looper storage in SDRAM
    const auto& rawStorages = *looperStorages.create();
    // build an array of storage pointers
    std::array<MonoOrStereoLooperStoragePtr, numLoopers> arrayOfStoragePtrs;
    for (size_t i = 0; i < numLoopers; i++)
        arrayOfStoragePtrs[i] = rawStorages[i];

    // initialize the looper controller that contains/controls the loopers
    looperController.create(
        arrayOfStoragePtrs,
        monoDownmixBuffer,
        temporaryBuffer,
        looperParameterProvider,
        audioSaveAndRecall);

    // init peak meters
    for (auto& peakMeter : peakMeters)
        peakMeter.init(0.5f);

    // init CPU load meter
    cpuLoadMeter.Init(seed.AudioSampleRate(), seed.AudioBlockSize());
}

// ===================================================================
// ===================================================================

void configurePlatform()
{
    seed.Configure();
    seed.Init(true /* enable 480MHz boost */);
    seed.SetAudioBlockSize(blockSize);
    seed.SetAudioSampleRate(sampleRate);

    fileIo.create();
}

void audioCallback(const float* const* in, float** out, size_t size)
{
    cpuLoadMeter.OnBlockStart();

    // update CV values
    looperParameterProvider->controlInputs_[0].pitchCvVolts =
        uiHardware->getKnobsAndCv().getCvVolts(CvInput::chA_speed);
    looperParameterProvider->controlInputs_[1].pitchCvVolts =
        uiHardware->getKnobsAndCv().getCvVolts(CvInput::chB_speed);
    looperParameterProvider->controlInputs_[2].pitchCvVolts =
        uiHardware->getKnobsAndCv().getCvVolts(CvInput::chC_speed);
    looperParameterProvider->controlInputs_[3].pitchCvVolts =
        uiHardware->getKnobsAndCv().getCvVolts(CvInput::chD_speed);
    looperParameterProvider->controlInputs_[0].volumeCvVolts =
        uiHardware->getKnobsAndCv().getCvVolts(CvInput::chA_volume);
    looperParameterProvider->controlInputs_[1].volumeCvVolts =
        uiHardware->getKnobsAndCv().getCvVolts(CvInput::chB_volume);
    looperParameterProvider->controlInputs_[2].volumeCvVolts =
        uiHardware->getKnobsAndCv().getCvVolts(CvInput::chC_volume);
    looperParameterProvider->controlInputs_[3].volumeCvVolts =
        uiHardware->getKnobsAndCv().getCvVolts(CvInput::chD_volume);

    // peak meters
    peakMeters[0].readPeaks(in[0]);
    peakMeters[1].readPeaks(in[1]);

    // process
    AudioBufferPtr<numChannelsPerLooper, const float> inputs(in, size);
    AudioBufferPtr<numChannelsPerLooper, float> outputs(out, size);
    outputs.fill(0.0f);
    looperController->process(inputs, outputs);

    // peak meters
    peakMeters[2].readPeaks(out[0]);
    peakMeters[3].readPeaks(out[1]);

    // clip outputs
    // TODO

    cpuLoadMeter.OnBlockEnd();
    // Set breakpoint here to check load
    const auto load = cpuLoadMeter.GetAvgCpuLoad();
    (void) load;
}

int main(void)
{
    configurePlatform();

    initDsp();

    initUi();

    // start audio
    seed.StartAudio(&audioCallback);

    // UI loop
    auto lastUpdate = daisy::System::GetNow();
    for (;;)
    {
        ui->process();
        uiHardware->processControls();

        // limit update rate to 50Hz
        constexpr auto kUpdateIntervalMs = 20;
        while (daisy::System::GetNow() < lastUpdate + kUpdateIntervalMs)
        {
            if (looperController->isSavingOrRecalling())
            {
                looperController->processSaveOrLoadOperation();
            }
        }
        lastUpdate = daisy::System::GetNow();
    }
}

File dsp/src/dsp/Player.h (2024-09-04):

/**
 * Copyright (C) Johannes Elliesen, 2021
 *
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
 * You should have received a copy of the GNU General Public License
 * along with this program. If not, see <http://www.gnu.org/licenses/>.
 */

#pragma once

#include "DspHelpers.h"
#include "AudioBuffer.h"

#ifndef MANUAL_INLINE
#    ifdef _MSC_VER
#        define MANUAL_INLINE __forceinline
#    else
#        define MANUAL_INLINE inline __attribute__((always_inline))
#    endif
#endif

enum class Direction
{
    forwards,
    backwards
};

template <typename ProcessorType,
          typename SpeedModulatorType,
          size_t sampleRateHz,
          size_t numChannels>
class Player
{
public:
    Player(AudioBufferPtr<numChannels, const float> bufferPtr) :
        sampleBuffer_(bufferPtr),
        playbackLength_(0),
        isPlaying_(false),
        playPos_(0.0f),
        lastProcessedSampleIdx_(-1)
    {
    }

    void reset()
    {
        processor_.reset();
        speedModulator_.reset();
        postGainSmoother_.reset(0);
        speedSmoother_.reset(0);
        playbackLength_ = 0;
        isPlaying_ = false;
        playPos_ = 0.0f;
        lastProcessedSampleIdx_ = -1;
        interpolationBuffer_[0].fill(0.0f);
        interpolationBuffer_[1].fill(0.0f);
    }

    void startPlaying(size_t loopLengthInSamples)
    {
        playbackLength_ = std::min(loopLengthInSamples, sampleBuffer_.size_);
        isPlaying_ = true;
        playPos_ = 0.0f;
        lastProcessedSampleIdx_ = wrapUpToPlaybackLength(-1);
        interpolationBuffer_[0].fill(0.0f);
        interpolationBuffer_[1].fill(0.0f);
    }

    void stopPlaying()
    {
        isPlaying_ = false;
    }

    bool isPlaying() const
    {
        return isPlaying_;
    }

    size_t getLoopLengthInSamples() const { return playbackLength_; }

    void process(float paramSpeed,
                 float speedModulationAmt,
                 Direction direction,
                 float paramPostProcessorGain,
                 const typename ProcessorType::Parameters& processorParameters,
                 AudioBufferPtr<numChannels, float> outputToAddTo,
                 ExponentialSmoother::TimeConstant postGainSmootherTimeConstant =
                     ExponentialSmoother::TimeConstant(0.05f, sampleRateHz, 1),
                 ExponentialSmoother::TimeConstant speedSmootherTimeConstant =
                     ExponentialSmoother::TimeConstant(0.5f, sampleRateHz, 1))
    {
        const auto postGainTarget = (isPlaying_) ? paramPostProcessorGain : 0.0f;
        const auto speedTarget = limit(paramSpeed, minSpeed_, maxSpeed_);
        const auto speedModulationAmtTarget = speedModulationAmt;

        if (playbackLength_ < 1)
            return;

        for (size_t i = 0; i < outputToAddTo.size_; i++)
        {
            const auto postGain = postGainSmoother_.smooth(postGainTarget, postGainSmootherTimeConstant);
            const auto speedModulation = speedModulator_.getAndAdvance() * speedModulationAmtTarget;
            const auto speed = speedModulation + speedSmoother_.smooth(speedTarget, speedSmootherTimeConstant);

            // the final two samples we need to interpolate for the current output sample
            const auto sampleAIdx = int(playPos_);
            const auto sampleBIdx = int(wrapDownToPlaybackLength(sampleAIdx + 1));
            // the interpolation point between the two samples
            const auto fractional = playPos_ - float(sampleAIdx);

            // process the raw, uninterpolated samples using the processor until both samples
            // are in the interpolation buffer
            int currentSampleIdx = lastProcessedSampleIdx_;
            while (currentSampleIdx != sampleBIdx)
            {
                lastProcessedSampleIdx_ = currentSampleIdx;
                currentSampleIdx = wrapDownToPlaybackLength(currentSampleIdx + 1);
                const auto indexToRead = (direction == Direction::forwards)
                                             ? currentSampleIdx
                                             : int(playbackLength_) - 1 - currentSampleIdx;

                for (size_t ch = 0; ch < numChannels; ch++)
                {
                    interpolationBuffer_[1][ch] = interpolationBuffer_[0][ch];
                    interpolationBuffer_[0][ch] = sampleBuffer_[ch][indexToRead];
                }
                processor_.process(interpolationBuffer_[0].data(), processorParameters);
            }

            for (size_t ch = 0; ch < numChannels; ch++)
            {
                const auto outSample = fractional * interpolationBuffer_[0][ch]
                                       + (1.0f - fractional) * interpolationBuffer_[1][ch];
                outputToAddTo[ch][i] += outSample * postGain;
            }
            lastProcessedSampleIdx_ = currentSampleIdx;

            // advance read position
            playPos_ += speed;
            playPos_ = wrapDownToPlaybackLength(playPos_);
        }
    }

    ProcessorType& getProcessor() { return processor_; }
    SpeedModulatorType& getSpeedModulator() { return speedModulator_; }

private:
    static constexpr float minSpeed_ = 0.25f;
    static constexpr float maxSpeed_ = 4.0f;

    template <typename T>
    MANUAL_INLINE T wrapDownToPlaybackLength(T value)
    {
        if (value >= T(playbackLength_))
            value -= T(playbackLength_);
        return value;
    }

    template <typename T>
    MANUAL_INLINE T wrapUpToPlaybackLength(T value)
    {
        if (value < T(0))
            value += T(playbackLength_);
        return value;
    }

    ExponentialSmoother postGainSmoother_;
    ExponentialSmoother speedSmoother_;

    AudioBufferPtr<numChannels, const float> sampleBuffer_;
    size_t playbackLength_;

    bool isPlaying_;
    float playPos_;
    int lastProcessedSampleIdx_;
    std::array<std::array<float, numChannels>, 2> interpolationBuffer_;

    SpeedModulatorType speedModulator_;
    ProcessorType processor_;
};

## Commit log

2021-09-28 fix crash when Player playback length < 1
    [Player.h]
2021-09-28 add samplerate template argument to Recorder
2021-10-09 add plateauMap()
2021-10-28 fix plateau map tests
2021-11-27 add KiCad projects and frontpanel SVG
    [AudioIO.sch, Channel_ADCs.sch, Channel_Buttons_And_Switches.sch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]
2022-01-25 hardware: update schematics & add BOM
    [AudioIO.sch, Channel_ADCs.sch, Channel_Buttons_And_Switches.sch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]
2022-01-25 feat: use new multi chip MAX11300 driver
2024-08-16 hardware: swap MAX11300 for ordinary multiplexers; PCB v1.1
    [AudioIO.kicad_sch, Channel_ADCs.kicad_sch, Channel_Buttons_And_Switches.kicad_sch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]
2024-08-16 hardware: delete obsolete KiCad 5 files
    [AudioIO.sch, Channel_ADCs.sch, Channel_Buttons_And_Switches.sch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]
2024-08-16 chore: add more KiCad files to .gitignore
2024-08-16 feat: add shift register based button input driver
2024-08-16 feat: add muxed-adc based CV and knob driver
2024-08-16 hardware: resave files with KiCad v7.0.4
    [AudioIO.kicad_sch, Channel_ADCs.kicad_sch, Channel_Buttons_And_Switches.kicad_sch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]
2024-08-16 hardware: resave BOM in .csv format
    [TapeLooper_BOM.csv, TapeLooper_BOM.ods]
2024-08-16 hardware: change audio I/O gain slightly
    [AudioIO.kicad_sch, TapeLooper_BOM.csv]
2024-08-16 hardware: fix resistor value
    [Channel_CVs.kicad_sch, TapeLooper_BOM.csv]
2024-08-16 hardware: fix reverse MCP6004 power pins
    [Channel_CVs.kicad_sch, TapeLooper_MainBoard.kicad_pcb]
2024-08-16 hardware: add missing SD card pullups
    [TapeLooper_BOM.csv, TapeLooper_MainBoard.kicad_pcb, TapeLooper_MainBoard.kicad_sch]
2024-08-16 docs: correct voltage range in comment
    [LooperParameterProvider.h]
2024-08-16 feat: apply CV inputs to volume and pitch
2024-08-16 feat: add a calibration page
2024-08-16 feat: add CV calibration storage to UiHardware
2024-08-16 feat: implement calibration UI page
2024-08-16 feat: close settings page before entering calibration page
2024-09-04 chore: replace sprout library with gcem
    sprout is no longer maintained.
    gcem is slimmer and under active development.
    [LooperController_gtest.cpp]
2024-09-04 tests: update existing UI tests
    They were not updated when the calibration feature was added.
    The "exit" tests are now split to make them less dependent on
    the behaviour of the other pages (we no longer have to go back
    to the page under test)
    [Ui_gtest.cpp]
2024-09-04 refactor: move calibration data types to UiHardwareTypes
    So that we can compile the UI tests
2024-09-04 tests: add missing return
    [Ui_gtest.cpp]
2024-09-04 fix: make MANUAL_INLINE a bit more portable
    [Player.h]
2026-04-13 chore: update gcc-arm-none-eabi to version 10-2020-q4-major
2026-04-13 feat: allow to abort a recording immediately
    this will be used when we want to restore a sample
    from storage while a recording is running
2026-04-13 feat: allow to prevent recording/playing in `TapeLooper`
    This will be used to lock the looper while we save/restore
    samples.
2026-04-13 feat: Allow to set playback length without recording
    this will be needed when we restore samples and write
    them to the buffer directly
2026-04-13 feat: UiHardware provides array of all channel LEDs
2026-05-22 fix: support hot plugging the SD card
    Reinitialization was previously not working because the
    SDMMC1 was stuck in a faulty state after it was detected
    that the SD card was removed.
    Resetting it fixes this issue.
    Now the SD card can be removed and plugged back in while
    the device is powered.

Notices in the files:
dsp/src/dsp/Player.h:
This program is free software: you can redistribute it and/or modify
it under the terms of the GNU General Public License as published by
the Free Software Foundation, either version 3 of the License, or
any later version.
